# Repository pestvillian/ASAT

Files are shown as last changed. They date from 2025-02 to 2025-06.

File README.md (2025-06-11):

**Automated Sample Agitation Transportation System**

We are an Electrical Engineering Capstone group from the University of California, Santa Cruz. Our project aims to design a more efficient, more cost-effective solution for medical staff and researchers to process human samples for imaging. 

Here is an overview of the file structure:
  - Five folders for each group member
  - "Motor-Controller-Board" contains PCB files for the Motor Controller PCB
  - "Touchscreen-Hardware" contains PCB files for the two revisions of the touchscreen PCB
  - "Firmware" contains the firmware for both PCBs

Finally, we created a poster to visually explain our project!

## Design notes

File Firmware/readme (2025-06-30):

To navigate the STM32 firmware folder,
Click on "Core" -> "SRC" -> "main.c" for the main file written by Dorjee Tenzing

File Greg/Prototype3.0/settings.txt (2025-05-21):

C:/Users/Greg/Desktop/ASAT/Greg/Prototype3.0/TempDirectory

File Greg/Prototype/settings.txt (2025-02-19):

C:/Users/geziegle/Desktop/ASAT/Greg/Prototype/Temp_directory

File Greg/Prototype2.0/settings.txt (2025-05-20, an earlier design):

C:/Users/Greg/Desktop/ASAT/Greg/Prototype2.0/temp_directory

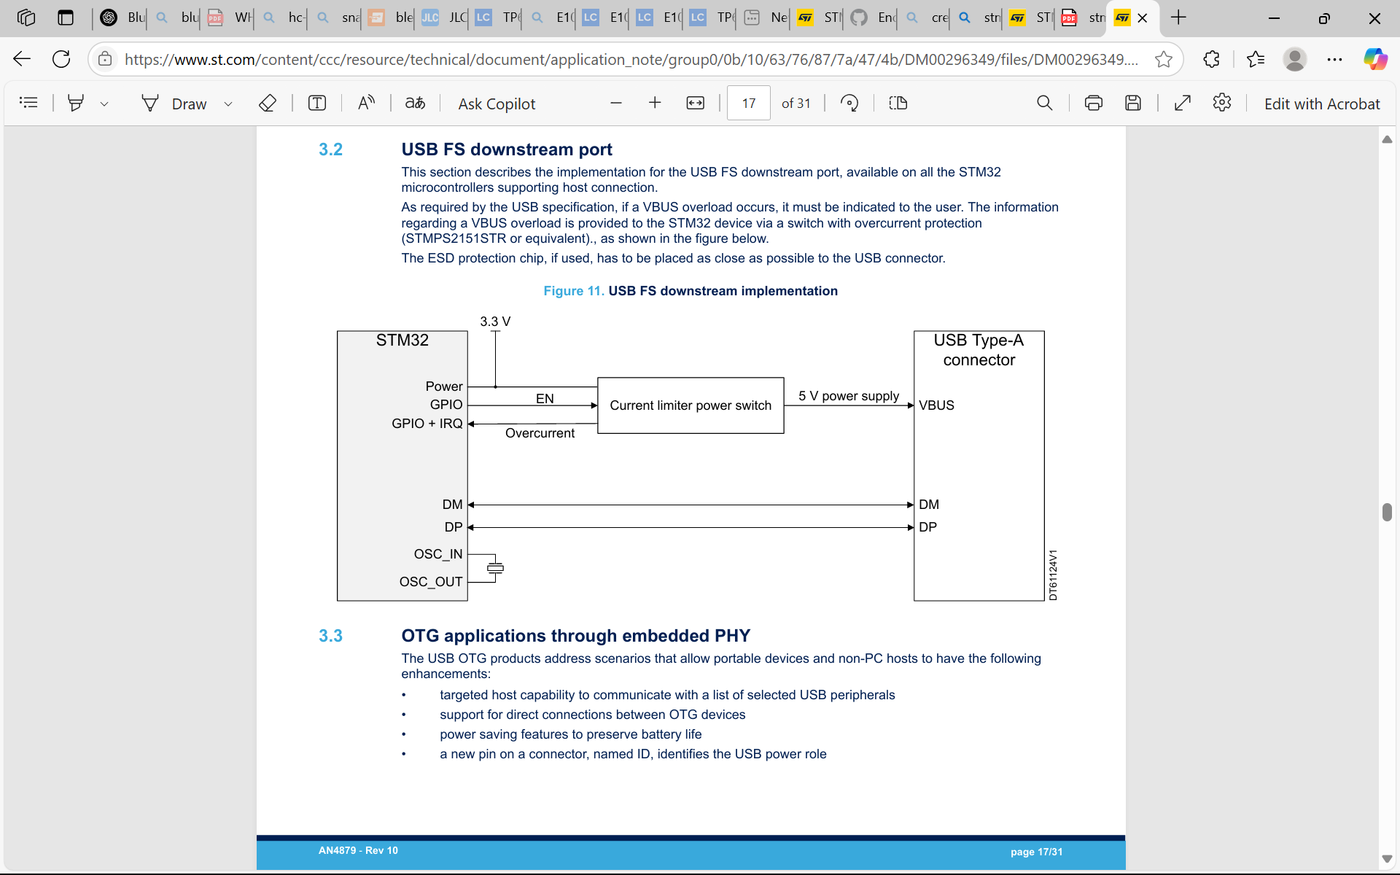
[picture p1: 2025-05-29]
Dorjee/datasheet_printouts/Touchscreen PCB Redesign/USB_OTG_FS Reference Circuit.png

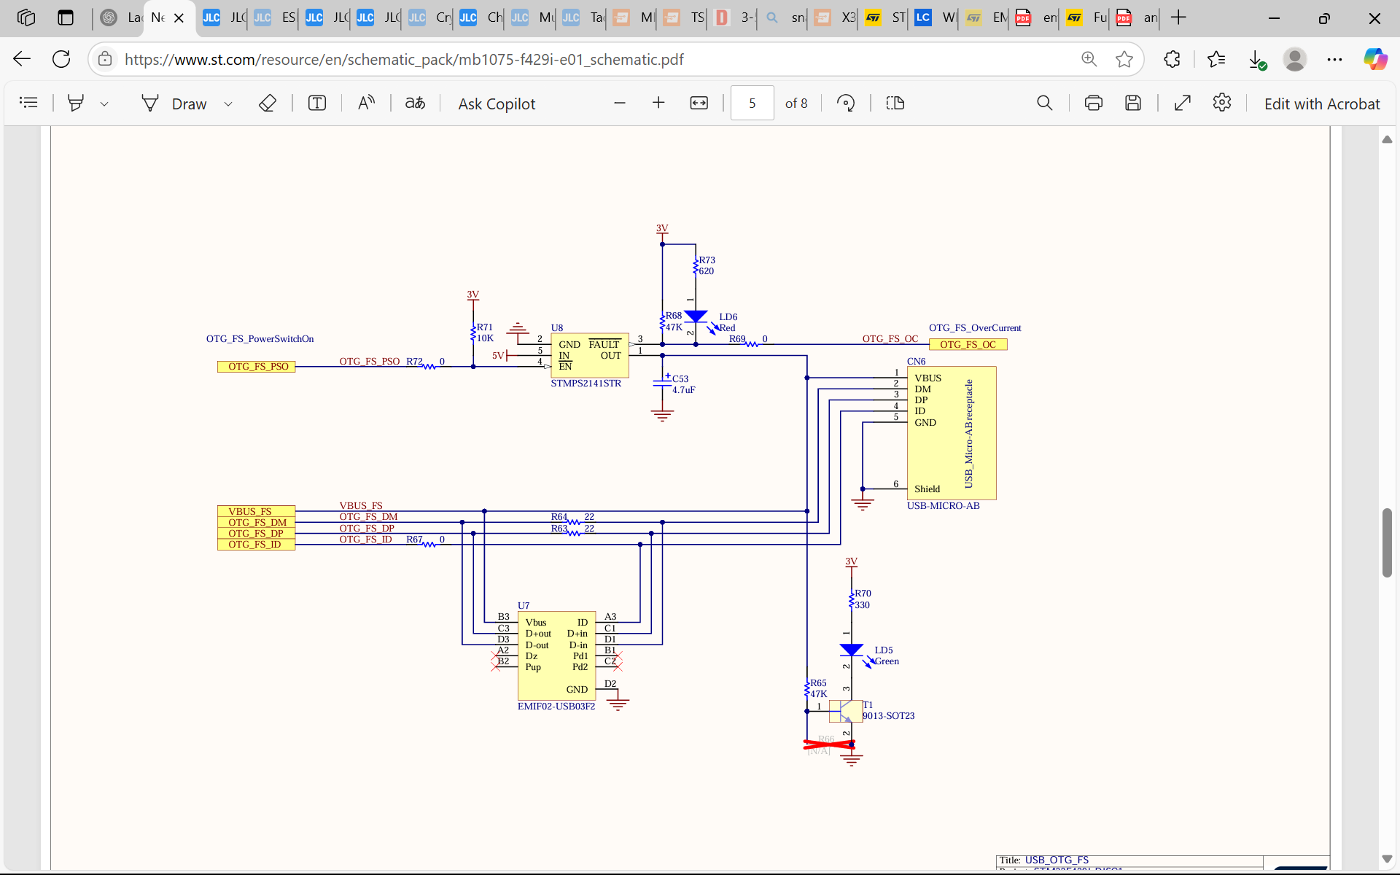
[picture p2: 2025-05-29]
Dorjee/datasheet_printouts/Touchscreen PCB Redesign/Disc Board USB Reference Circuit.png

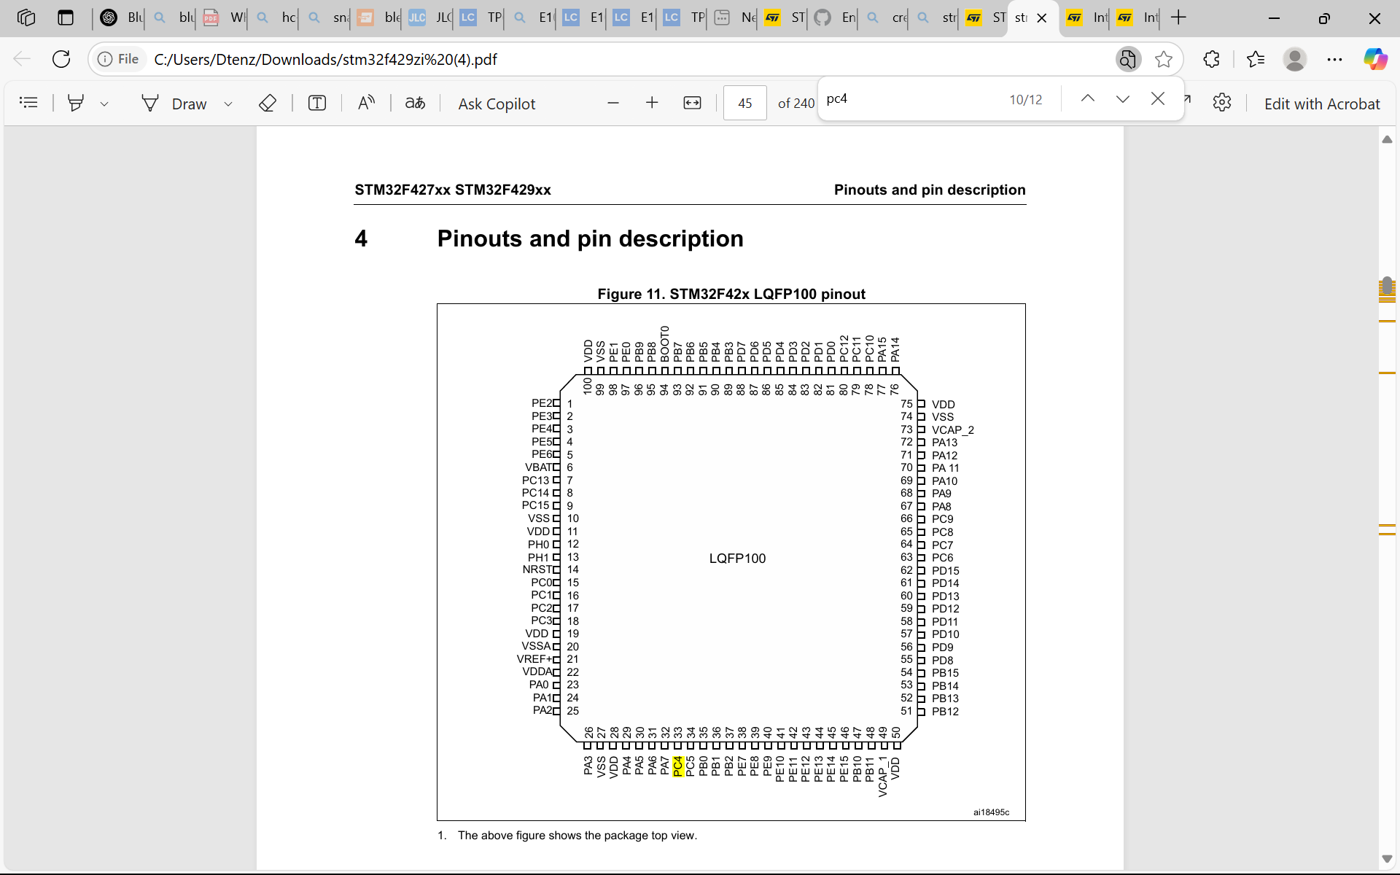
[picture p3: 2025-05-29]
Dorjee/datasheet_printouts/Touchscreen PCB Redesign/STM32F429VIT6 Pinout.png

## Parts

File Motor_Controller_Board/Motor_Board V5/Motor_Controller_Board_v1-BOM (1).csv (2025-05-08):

Reference | Qty | Value | DNP | Footprint | Datasheet | MPN | LCSC Part Number | Manufacturer
U401,U402,U403 | 3 | A4988 |  | Package_DFN_QFN:QFN-28-1EP_5x5mm_P0.5mm_EP3.25x3.25mm_ThermalVias | kicad-embed://A4988-Datasheet.pdf | A4988SETTR-T | C38437 | Allegro MicroSystems, LLC
U301 | 1 | ESP32-C6-MINI-1 |  | Espressif:ESP32-C6-MINI-1U | https://www.espressif.com/sites/default/files/documentation/esp32-c6-mini-1_mini-1u_datasheet_en.pdf | ESP32-C6-MINI-1U-H4 | C20627095 | Espressif Systems
U202 | 1 | AMS1117 |  | Package_TO_SOT_SMD:SOT-223-3_TabPin2 | http://www.advanced-monolithic.com/pdf/ds1117.pdf | AMS1117-3.3 | C6186 | Advanced Monolithic Systems
U201 | 1 | TP6841S6 |  | Package_TO_SOT_SMD:SOT-23-6 | https://jlcpcb.com/api/file/downloadByFileSystemAccessId/8588919820586377216 | TP6841S6-A | C2844924 | TECH PUBLIC
SW301,SW302 | 2 | SW_Push |  | Button_Switch_SMD:SW_Push_1P1T_XKB_TS-1187A | ~ | TS-1187A-B-A-B | C318884 | XKB Connection
R417 | 1 | 12k |  | Resistor_SMD:R_0603_1608Metric | ~ | 0603WAF1202T5E | C22790 | UNI-ROYAL(Uniroyal Elec)
R409,R410,R412,R414,R421,R422 | 6 | 75m |  | Resistor_SMD:R_1206_3216Metric | ~ | CR1206FR075P05R | C149663 | Ever Ohms Tech
R406,R408,R420 | 3 | 24k |  | Resistor_SMD:R_0603_1608Metric | ~ | 0603WAF2402T5E | C23352 | UNI-ROYAL(Uniroyal Elec)
R405,R407,R419 | 3 | 10R |  | Resistor_SMD:R_0603_1608Metric | ~ | 0603WAF100JT5E | C22859 | UNI-ROYAL(Uniroyal Elec)
R403 | 1 | 18k |  | Resistor_SMD:R_0603_1608Metric | ~ | 0603WAF1802T5E | C25810 | UNI-ROYAL(Uniroyal Elec)
R402,R404,R418 | 3 | 4k7 |  | Resistor_SMD:R_0603_1608Metric | ~ | 0603WAF4701T5E | C23162 | UNI-ROYAL(Uniroyal Elec)
R302,R303 | 2 | 0R |  | Resistor_SMD:R_0603_1608Metric | ~ | 0603WAF0000T5E | C21189 | UNI-ROYAL(Uniroyal Elec)
R301,R304,R401,R411,R415,R423 | 6 | 10k |  | Resistor_SMD:R_0603_1608Metric | ~ | 0603WAF1002T5E | C25804 | UNI-ROYAL(Uniroyal Elec)
R204 | 1 | 13k |  | Resistor_SMD:R_0603_1608Metric | ~ | 0603WAF1302T5E | C22797 | UNI-ROYAL(Uniroyal Elec)
R203 | 1 | 68k |  | Resistor_SMD:R_0603_1608Metric | ~ | 0603WAF6802T5E | C23231 | UNI-ROYAL(Uniroyal Elec)
R202,R413,R416,R424 | 4 | 100k |  | Resistor_SMD:R_0603_1608Metric | ~ | 0603WAF1003T5E | C25803 | UNI-ROYAL(Uniroyal Elec)
R201 | 1 | 5k1 |  | Resistor_SMD:R_0603_1608Metric | ~ | 0603WAF5101T5E | C23186 | UNI-ROYAL(Uniroyal Elec)
L201 | 1 | 22u |  | Inductor_SMD:L_10.4x10.4_H4.8 | ~ | SMDRH105R-220MT | C10165 | SXN(Shun Xiang Nuo Elec)
J302 | 1 | USB_B_Micro |  | Connector_USB:USB_Micro-B_Molex-105017-0001 | ~ | MicroXNJ | C404969 | SHOU HAN
D401,D402,D403 | 3 | SMAJ28A |  | Diode_SMD:D_SMA | ~ | SMAJ28A | C148227 | Littelfuse
D303 | 1 | SS14 |  | Diode_SMD:D_SMA | ~ | SS14 | C2480 | MDD(Microdiode Semiconductor)
D301,D302,D304 | 3 | PSM712-LF-T7 |  | Package_TO_SOT_SMD:SOT-23 | ~ | PSM712-LF-T7 | C32677 | ProTek Devices
D201 | 1 | RED |  | LED_SMD:LED_0603_1608Metric | ~ | KT-0603R | C2286 | Hubei KENTO Elec
C410,C415,C423 | 3 | 100u |  | Capacitor_SMD:CP_Elec_6.3x7.7 | ~ | RVT1V101M0607 | C3339 | Honor Elec
C407,C411,C420 | 3 | 220n |  | Capacitor_SMD:C_0805_2012Metric | ~ | CL21B224KBFNNNE | C5378 | Samsung Electro-Mechanics
C304 | 1 | 1u |  | Capacitor_SMD:C_0402_1005Metric | ~ | CL05A105KA5NQNC | C52923 | Samsung Electro-Mechanics
C301,C303,C305,C401,C403,C417 | 6 | 100n |  | Capacitor_SMD:C_0402_1005Metric | ~ | CL05B104KO5NNNC | C1525 | Samsung Electro-Mechanics
C205,C206,C302,C402,C404,C418 | 6 | 22u |  | Capacitor_SMD:C_0603_1608Metric | ~ | CL21A226MAQNNNE | C45783 | Samsung Electro-Mechanics
C202,C204 | 2 | 22u |  | Capacitor_SMD:C_2220_5750Metric | ~ | FS55X226K500EHG | C784103 | PSA(Prosperity Dielectrics)
C201,C203,C405,C406,C408,C409,C412,C413,C414,C416,C419,C421,C422,C424 | 14 | 100n |  | Capacitor_SMD:C_0603_1608Metric | ~ | CC0603KRX7R9BB104 | C14663 | YAGEO

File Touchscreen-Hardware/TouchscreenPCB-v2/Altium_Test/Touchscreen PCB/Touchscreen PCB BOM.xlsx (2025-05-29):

Designator | Name | Description | Manufacturer | Manufacturer Part Number | LCSC
C1 | 100n | Capacitor SMD 0402 | Samsung Electro-Mechanics | CL05B104KO5NNNC | C1525
C2 | 10u | Capacitor SMD 0603 | *Samsung Electro-Mechanics | CL10A106MA8NRNC | C96446
C3 | 22u | Capacitor SMD 0805 | Samsung Electro-Mechanics | CL21A226MAQNNNE | C45783
C4 | 22u | Capacitor SMD 0805 | Samsung Electro-Mechanics | CL21A226MAQNNNE | C45783
C5 | 10u | Capacitor SMD 0603 | *Samsung Electro-Mechanics | CL10A106MA8NRNC | C96446
C6 | 100n | Capacitor SMD 0402 | Samsung Electro-Mechanics | CL05B104KO5NNNC | C1525
C7 | 100n | Capacitor SMD 0402 | Samsung Electro-Mechanics | CL05B104KO5NNNC | C1525
C8 | 100n | Capacitor SMD 0402 | Samsung Electro-Mechanics | CL05B104KO5NNNC | C1525
C9 | 100n | Capacitor SMD 0402 | Samsung Electro-Mechanics | CL05B104KO5NNNC | C1525
C10 | 100n | Capacitor SMD 0402 | Samsung Electro-Mechanics | CL05B104KO5NNNC | C1525
C11 | 100n | Capacitor SMD 0402 | Samsung Electro-Mechanics | CL05B104KO5NNNC | C1525
C12 | 100n | Capacitor SMD 0402 | Samsung Electro-Mechanics | CL05B104KO5NNNC | C1525
C13 | 10u | Capacitor SMD 0603 | *Samsung Electro-Mechanics | CL10A106MA8NRNC | C96446
C14 | 1u | Capacitor SMD 0402 | Samsung Electro-Mechanics | CL05A105KA5NQNC | C52923
C15 | 100n | Capacitor SMD 0402 | Samsung Electro-Mechanics | CL05B104KO5NNNC | C1525
C16 | 10p | Capacitor SMD 0402 | Samsung Electro-Mechanics | CL05C100JB5NNNC | C32949
C17 | 10p | Capacitor SMD 0402 | Samsung Electro-Mechanics | CL05C100JB5NNNC | C32949
C18 | 2u2 | Capacitor SMD 0603 | Samsung Electro-Mechanics | CL10A225KO8NNNC | C23630
C19 | 2u2 | Capacitor SMD 0603 | Samsung Electro-Mechanics | CL10A225KO8NNNC | C23630
C20 | 100n | Capacitor SMD 0402 | Samsung Electro-Mechanics | CL05B104KO5NNNC | C1525
C21 | 4u7 | Capacitor SMD 0603 | Samsung Electro-Mechanics | CL10A475KO8NNNC | C19666
D1 | RED | LED 0603 RED SMD | Hubei KENTO Elec | KT-0603R | C2286
D2 | SMBJ6.5CA | 53.57A 600W 11.2V 7.22V Bidirectional 6.5V SMB ESD and Surge Protection (TVS/ESD) ROHS | hongjiacheng | SMBJ6.5CA | C7420377
D3 | SMBJ6.5CA | 53.57A 600W 11.2V 7.22V Bidirectional 6.5V SMB ESD and Surge Protection (TVS/ESD) ROHS | hongjiacheng | SMBJ6.5CA | C7420377
D4 | SMBJ6.5CA | 53.57A 600W 11.2V 7.22V Bidirectional 6.5V SMB ESD and Surge Protection (TVS/ESD) ROHS | hongjiacheng | SMBJ6.5CA | C7420377
FB1 | 120R | Ferrite Bead SMD 0603 | Murata Electronics | BLM18PG121SN1D | C14709
J1 | SSW-117-01-T-D | SQ Post Socket, Through-hole, Vertical, -55 to 105 degC, 2.54 mm Pitch, 34-Pin, Female, RoHS | Samtec
J2 | 473460001 | CONN RCPT USB2.0 MICRO B SMD R/A | Molex | 473460001 | C132560
P1 | 22-23-2021 | Male Header, Pitch 2.54 mm, 1 x 2 Position, Height 10.67 mm, Tail Length 3.56 mm, 0 to 75 degC, RoHS, Bulk
P2 | 61300611121
P3 | 22-27-2041 | Male Header, Pitch 2.54 mm, 1 x 4 Position, Height 11.7 mm, Tail Length 3.56 mm, RoHS, Bulk | Molex
R1 | 4k7 | Resistor SMD 0402 | UNI-ROYAL(Uniroyal Elec) | 0402WGF4701TCE | C25900
R2 | 220 | Resistor SMD 0402 | UNI-ROYAL(Uniroyal Elec) | 0402WGF2200TCE | C25091
R3 | 220 | Resistor SMD 0402 | UNI-ROYAL(Uniroyal Elec) | 0402WGF2200TCE | C25091
R4 | 10k | Resistor SMD 0402 | UNI-ROYAL(Uniroyal Elec) | 0402WGF1002TCE | C25744
R5 | 10k | Resistor SMD 0402 | UNI-ROYAL(Uniroyal Elec) | 0402WGF1002TCE | C25744
R6 | 47k | Resistor SMD 0402 | UNI-ROYAL(Uniroyal Elec) | 0402WGF4702TCE | C25792
R7 | 0 | Resistor SMD 0402 | UNI-ROYAL(Uniroyal Elec) | 0402WGF0000TCE | C17168
SW1 |  | None Without 50mA 5.1mm 100000 Times 160gf 12V 5.1mm 1.5mm Round Button Standing paste SPST SMD Tactile Switches ROHS | XKB Connection | TS-1187A-B-A-B | C318884
U1 | AMS1117-3.3 | LDO Voltage Regulators 1A, 3.3V | Advanced Monolithic Systems | AMS1117-3.3 | C6186
U2 | STM32F429VIT6 | ARM Cortex-M4 32-bit MCU+FPU, 225 DMIPS, 2048 kB Flash, 256 kB Internal RAM, 82 I/Os, 100-pin LQFP, -40 to 85 degC, Tray | STMicroelectronics | STM32F429VIT6 | C92002
U3 | STMPS2141STR | STMPS2141STR STMPS Series 1 Channel 5.5 V 500 mA 200 mOhm High Side Power Switch - SOT-23-5 | STMicroelectronics | STMPS2141STR | C54624
X1 | 16MHz |  | YXC Crystal Oscillators | X322516MLB4SI | C13738

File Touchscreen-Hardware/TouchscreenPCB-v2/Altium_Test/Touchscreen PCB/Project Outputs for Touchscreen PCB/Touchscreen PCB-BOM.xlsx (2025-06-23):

Designator | Quantity | Name | Description | Manufacturer | Manufacturer Part Number | LCSC | Manufacturer 1 | Manufacturer Part Number 1
C1, C6, C7, C8, C9, C10, C11, C12, C15, C20 | 10 | 100n | Capacitor SMD 0402 | Samsung Electro-Mechanics | CL05B104KO5NNNC | C1525
C2, C5, C13 | 3 | 10u | Capacitor SMD 0603 | *Samsung Electro-Mechanics | CL10A106MA8NRNC | C96446
C3, C4 | 2 | 22u | Capacitor SMD 0805 | Samsung Electro-Mechanics | CL21A226MAQNNNE | C45783
C14 | 1 | 1u | Capacitor SMD 0402 | Samsung Electro-Mechanics | CL05A105KA5NQNC | C52923
C16, C17 | 2 | 10p | Capacitor SMD 0402 | Samsung Electro-Mechanics | CL05C100JB5NNNC | C32949
C18, C19 | 2 | 2u2 | Capacitor SMD 0603 | Samsung Electro-Mechanics | CL10A225KO8NNNC | C23630
C21 | 1 | 4u7 | Capacitor SMD 0603 | Samsung Electro-Mechanics | CL10A475KO8NNNC | C19666
D1 | 1 | RED | LED 0603 RED SMD | Hubei KENTO Elec | KT-0603R | C2286
FB1 | 1 | 120R | Ferrite Bead SMD 0603 | Murata Electronics | BLM18PG121SN1D | C14709
J1 | 1 | 2x17 Odd-Even | SQ Post Socket, Through-hole, Vertical, -55 to 105 degC, 2.54 mm Pitch, 34-Pin, Female, RoHS | Samtec |  |  | Samtec | SSW-117-01-T-D
J2 | 1 | 473460001 | CONN RCPT USB2.0 MICRO B SMD R/A | Molex | 473460001 | C132560 | Molex | 47346-0001
J3 | 1 | 691102710002 |  |  |  |  | Wurth Electronics | 691102710002
J4, J5, J6 | 3 | B2B-XH-A(LF)(SN) | CONN HEADER VERT 2POS 2.5MM |  |  |  | JST | B2B-XH-A(LF)(SN)
J7 | 1 | B4B-XH-A(LF)(SN) | CONN HEADER VERT 4POS 2.5MM |  |  |  | JST | B4B-XH-A(LF)(SN)
P2 | 1 |  |  |  |  |  | Wurth Electronics | 61300611121
Q1 | 1 | IRLZ44NPbF | MOSFET N-CH 55V 47A TO220AB |  |  |  | Infineon | IRLZ44NPBF
R1 | 1 | 4k7 | Resistor SMD 0402 | UNI-ROYAL(Uniroyal Elec) | 0402WGF4701TCE | C25900
R2, R3 | 2 | 220 | Resistor SMD 0402 | UNI-ROYAL(Uniroyal Elec) | 0402WGF2200TCE | C25091
R4, R5, R9 | 3 | 10k | Resistor SMD 0402 | UNI-ROYAL(Uniroyal Elec) | 0402WGF1002TCE | C25744
R6 | 1 | 47k | Resistor SMD 0402 | UNI-ROYAL(Uniroyal Elec) | 0402WGF4702TCE | C25792
R7 | 1 | 0 | Resistor SMD 0402 | UNI-ROYAL(Uniroyal Elec) | 0402WGF0000TCE | C17168
R8 | 1 | 1k | Resistor SMD 0402 | UNI-ROYAL(Uniroyal Elec) | 0402WGF1001TCE | C11702
SW1 | 1 |  | None Without 50mA 5.1mm 100000 Times 160gf 12V 5.1mm 1.5mm Round Button Standing paste SPST SMD Tactile Switches ROHS | XKB Connection | TS-1187A-B-A-B | C318884
U1 | 1 | AMS1117-3.3 | LDO Voltage Regulators 1A, 3.3V | Advanced Monolithic Systems | AMS1117-3.3 | C6186 | Advanced Monolithic Systems | AMS1117-3.3
U2 | 1 | STM32F429VIT6 | ARM Cortex-M4 32-bit MCU+FPU, 225 DMIPS, 2048 kB Flash, 256 kB Internal RAM, 82 I/Os, 100-pin LQFP, -40 to 85 degC, Tray | STMicroelectronics | STM32F429VIT6 | C92002 | STMicroelectronics | STM32F429VIT6
U3 | 1 | STMPS2141STR | STMPS2141STR STMPS Series 1 Channel 5.5 V 500 mA 200 mOhm High Side Power Switch - SOT-23-5 | STMicroelectronics | STMPS2141STR | C54624 | STMicroelectronics | STMPS2141STR
X1 | 1 | 16MHz |  | YXC Crystal Oscillators | X322516MLB4SI | C13738

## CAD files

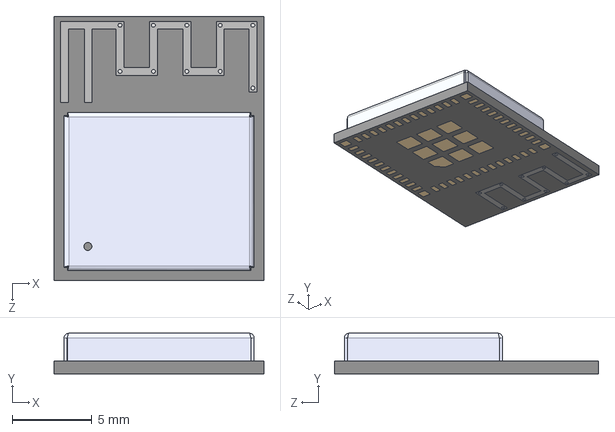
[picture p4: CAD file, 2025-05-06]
Motor_Controller_Board/Motor_Controller_Board/ESP32-C6-MINI-1-N4.STEP
13.2 x 2.55 x 16.6 mm

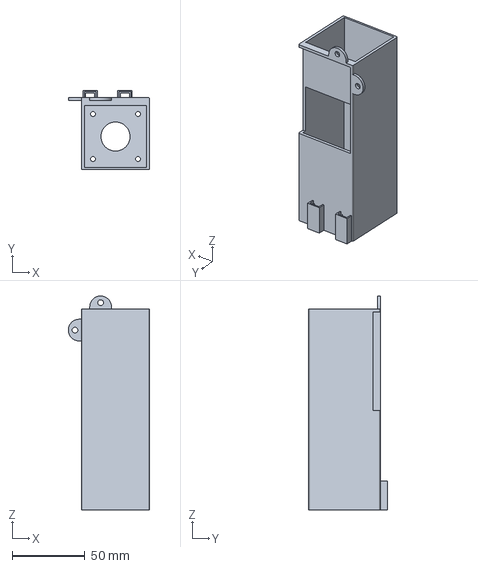
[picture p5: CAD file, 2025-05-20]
Greg/3DPrints-Exports/PrimaryBodyV6.3mf
56.0 x 54.7 x 147.3 mm

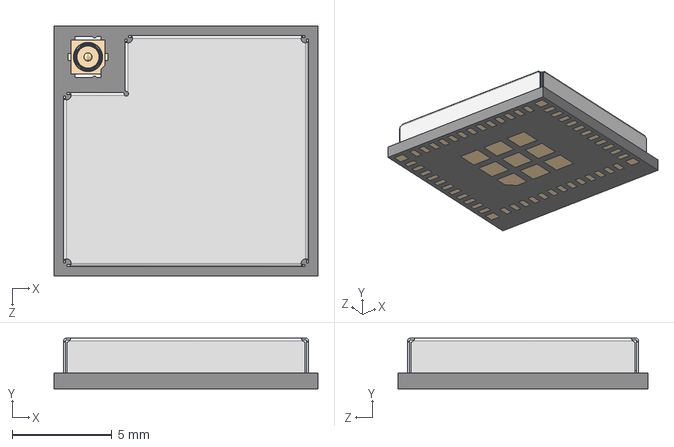
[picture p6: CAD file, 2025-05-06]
Motor_Controller_Board/Motor_Controller_Board/ESP32-C3-MINI-1U-N4--3DModel-STEP-269445.STEP
13.2 x 2.55 x 12.5 mm

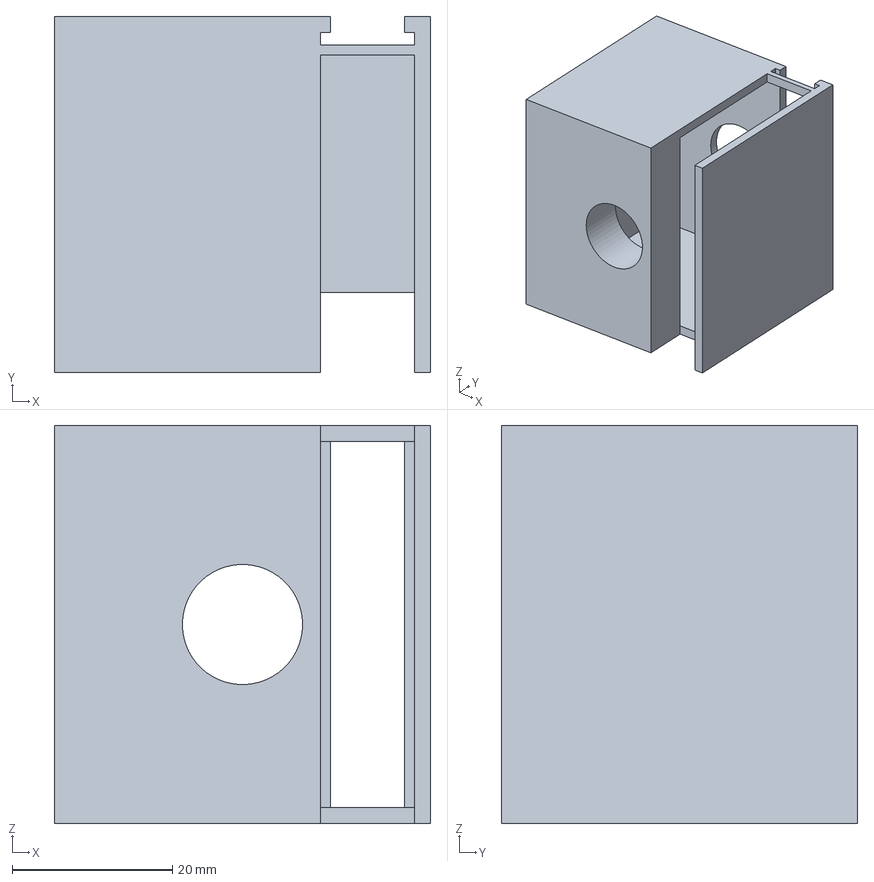
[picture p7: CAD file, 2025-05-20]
Greg/3DPrints-Exports/SecondaryBody2.3mf
47.0 x 44.5 x 49.7 mm

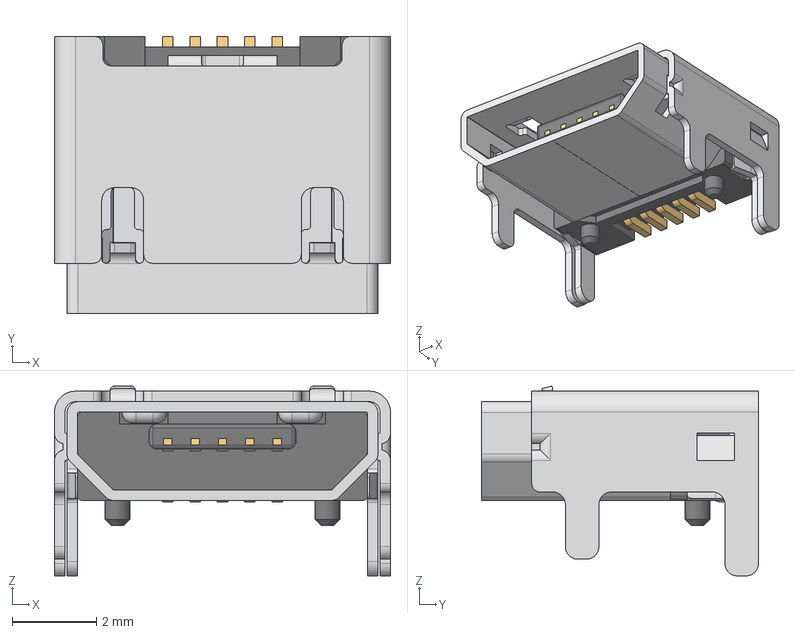
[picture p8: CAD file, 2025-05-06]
Motor_Controller_Board/Motor_Controller_Board/Download_STP_629105150521_rev1.stp
8.00 x 6.60 x 4.52 mm
629105150521_Housing
629105150521_Pin1 x 4
629105150521_Pin2
629105150521_Shielding2
629105150521_Shielding

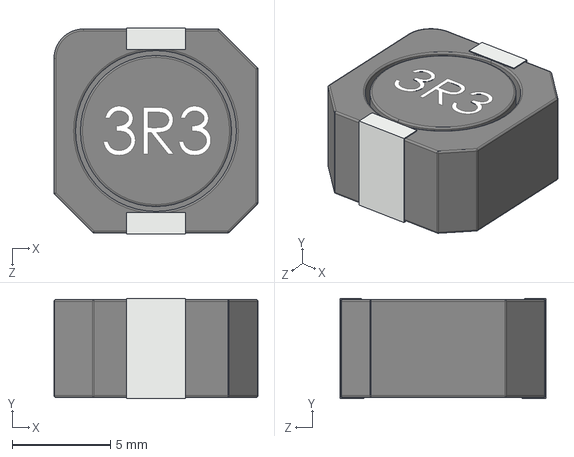
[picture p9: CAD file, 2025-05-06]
Motor_Controller_Board/Motor_Controller_Board/User Library-SMDRH105R.STEP
10.4 x 5.12 x 10.5 mm

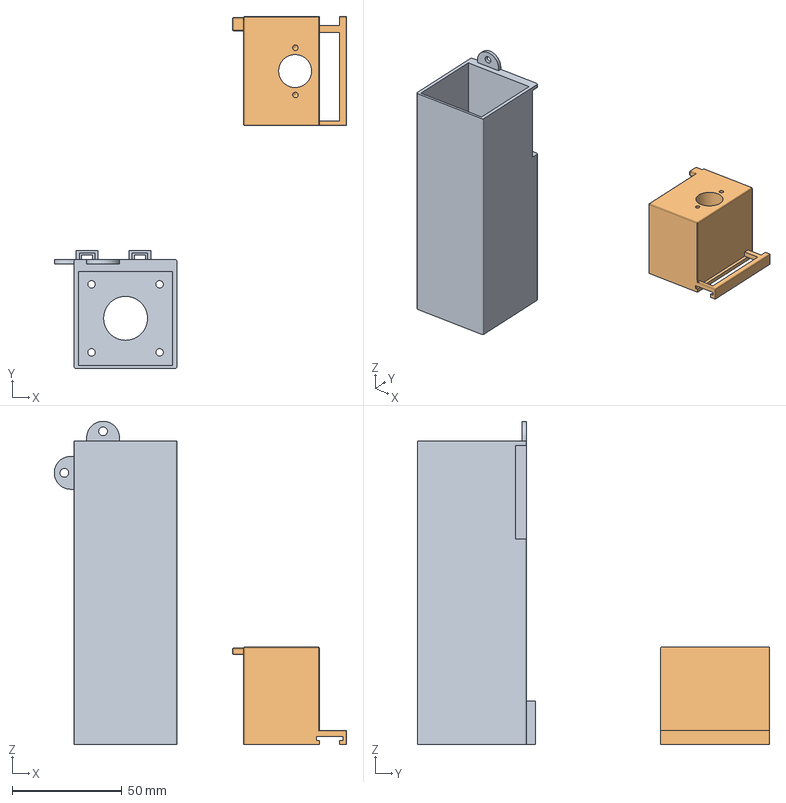
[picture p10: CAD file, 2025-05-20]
Greg/3DPrints-Exports/PrimarySecondaryBodies.3mf
133.2 x 160.3 x 147.3 mm
PrimaryBodyV4.stl
SecondaryBodyV4.stl

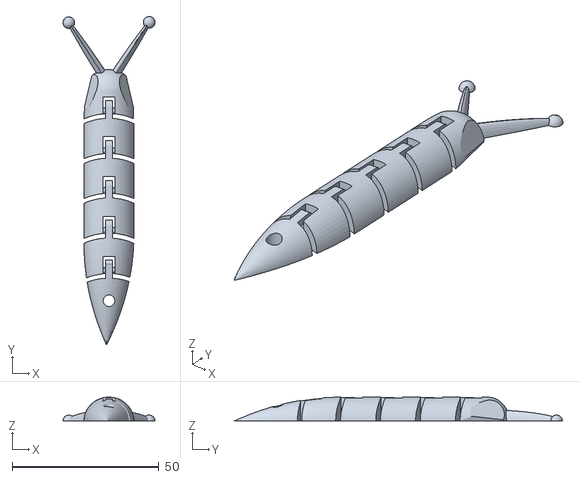
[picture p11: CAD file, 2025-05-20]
Greg/3DPrints-Exports/articulated_slug_key_chain.stl
31.4 x 111.9 x 8.12

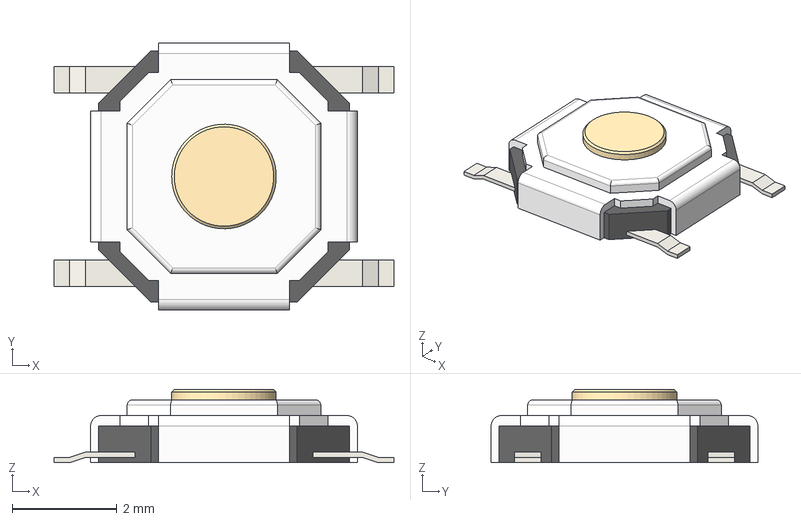
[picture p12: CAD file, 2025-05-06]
Motor_Controller_Board/Motor_Controller_Board/TS-1187A.step
6.50 x 5.10 x 1.40 mm

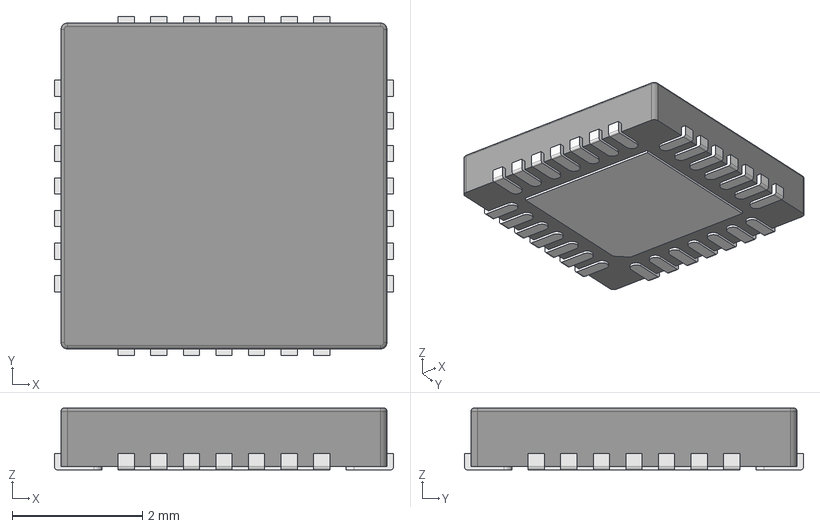
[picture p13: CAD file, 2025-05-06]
Motor_Controller_Board/Motor_Controller_Board/QFN28.step
5.20 x 5.20 x 0.95 mm

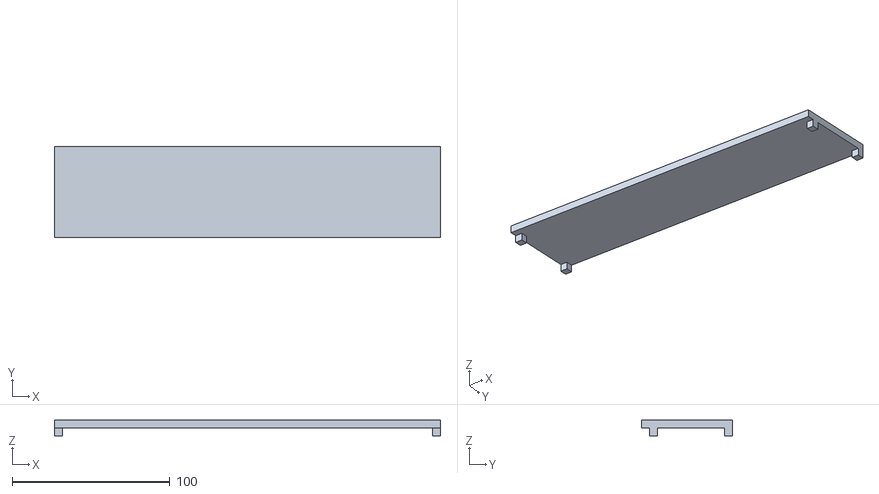
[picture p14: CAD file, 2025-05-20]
Greg/3DPrints-Exports/Drawer_Lid.stl
245.0 x 57.5 x 10.0

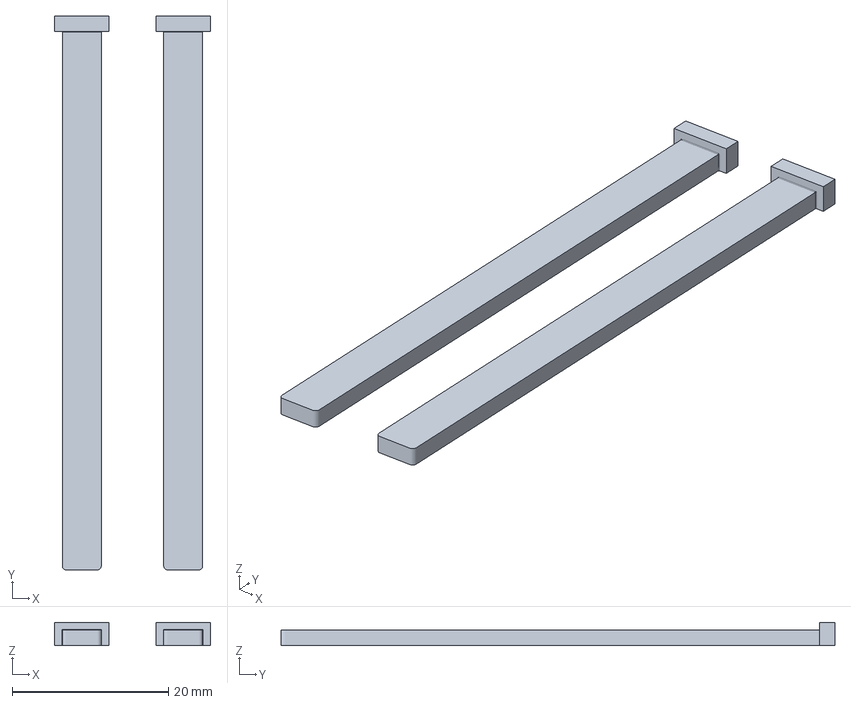
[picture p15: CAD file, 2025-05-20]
Greg/3DPrints-Exports/BackGuidesV2.3mf
20.0 x 71.0 x 3.00 mm

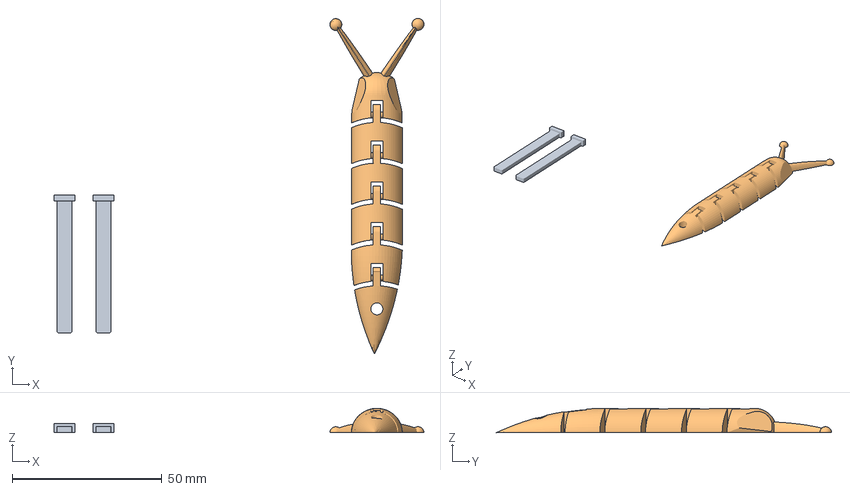
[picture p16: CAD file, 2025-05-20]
Greg/3DPrints-Exports/BackGuides.3mf
123.4 x 111.9 x 8.12 mm
BackGuides.stl
articulated_slug_key_chain.stl

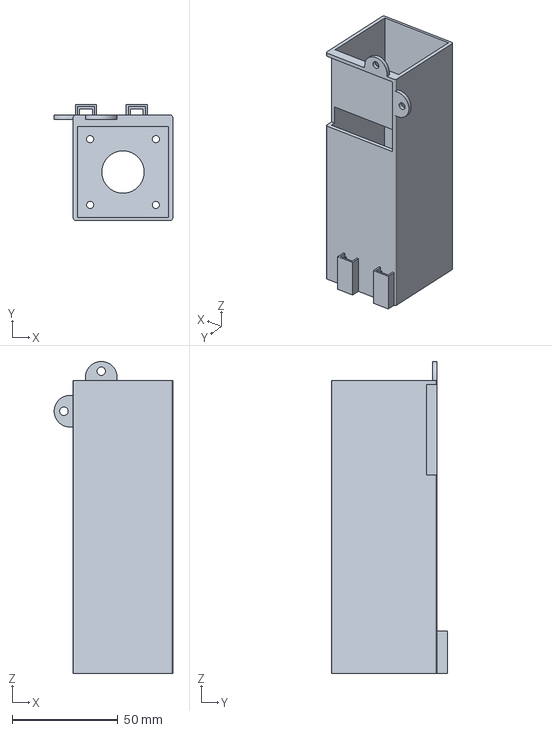
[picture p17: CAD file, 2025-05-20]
Greg/3DPrints-Exports/SecondaryBodyV5.3mf
56.0 x 54.7 x 147.3 mm

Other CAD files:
Greg/3DPrints-Exports/PrimaryBodyV9WLM.4.2.stl
Greg/3DPrints-Exports/scraper.gcode.3mf
Motor_Controller_Board/Motor_Controller_Board/Screw Terminal Block 5mm 2-way.step
Greg/3DPrints-Exports/BackGuides.stl
Greg/3DPrints-Exports/BackGuidesV2.stl
Greg/3DPrints-Exports/PrimaryBodyV4.stl
Greg/3DPrints-Exports/PrimaryBodyV5.stl
Greg/3DPrints-Exports/PrimaryBodyV6.stl
Greg/3DPrints-Exports/SecondaryBody2.stl
Greg/3DPrints-Exports/SecondaryBodyV3.3mf
Greg/3DPrints-Exports/SecondaryBodyV3.stl
Greg/3DPrints-Exports/SecondaryBodyV4.stl
Greg/3DPrints-Exports/SecondaryBodyV5.stl
Motor_Controller_Board/Motor_Controller_Board/Screw Terminal Block 5mm 4-way.step
Motor_Controller_Board/Motor_Controller_Board/User Library-SMDRH105R.sldprt
Motor_Controller_Board/motor_controller_board_3D/Screw Terminal Block 5mm 2-way.step
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

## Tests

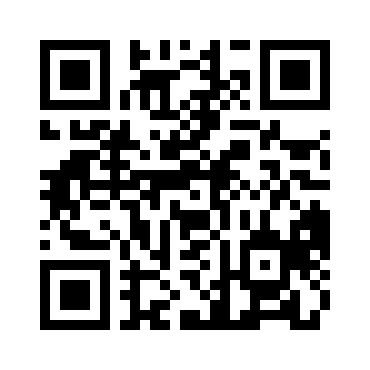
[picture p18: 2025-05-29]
Greg/KVgui/test_dir/test.exe_QR.png

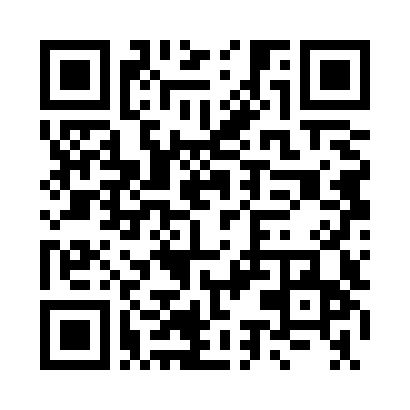
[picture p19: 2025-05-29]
Greg/KVgui/test_dir/my test_QR.png

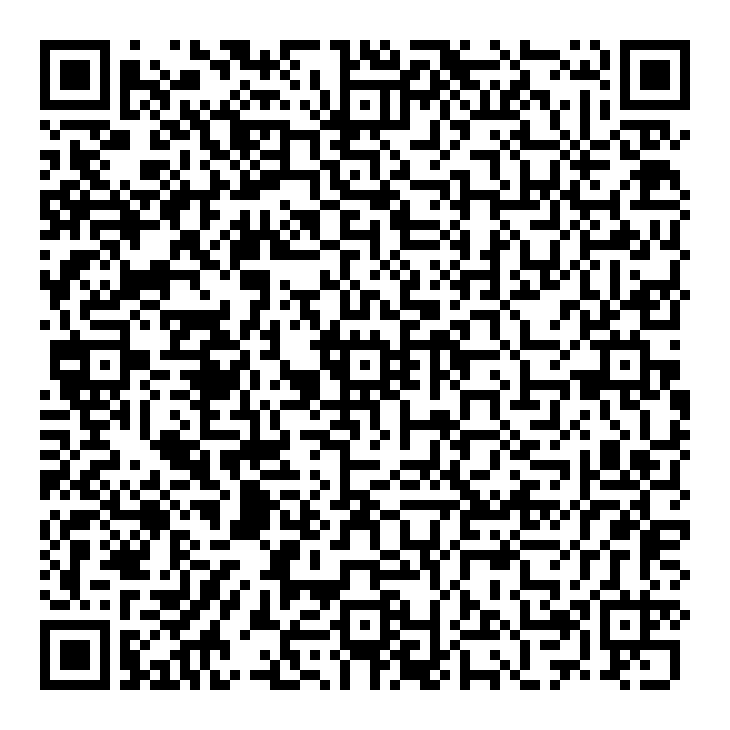
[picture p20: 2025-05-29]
Greg/KVgui/test_dir/gamze_QR.png

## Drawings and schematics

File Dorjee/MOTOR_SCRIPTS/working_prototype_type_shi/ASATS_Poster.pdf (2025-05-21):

## Agitation Body Design

# Automated Sample Agitation Transportation System:

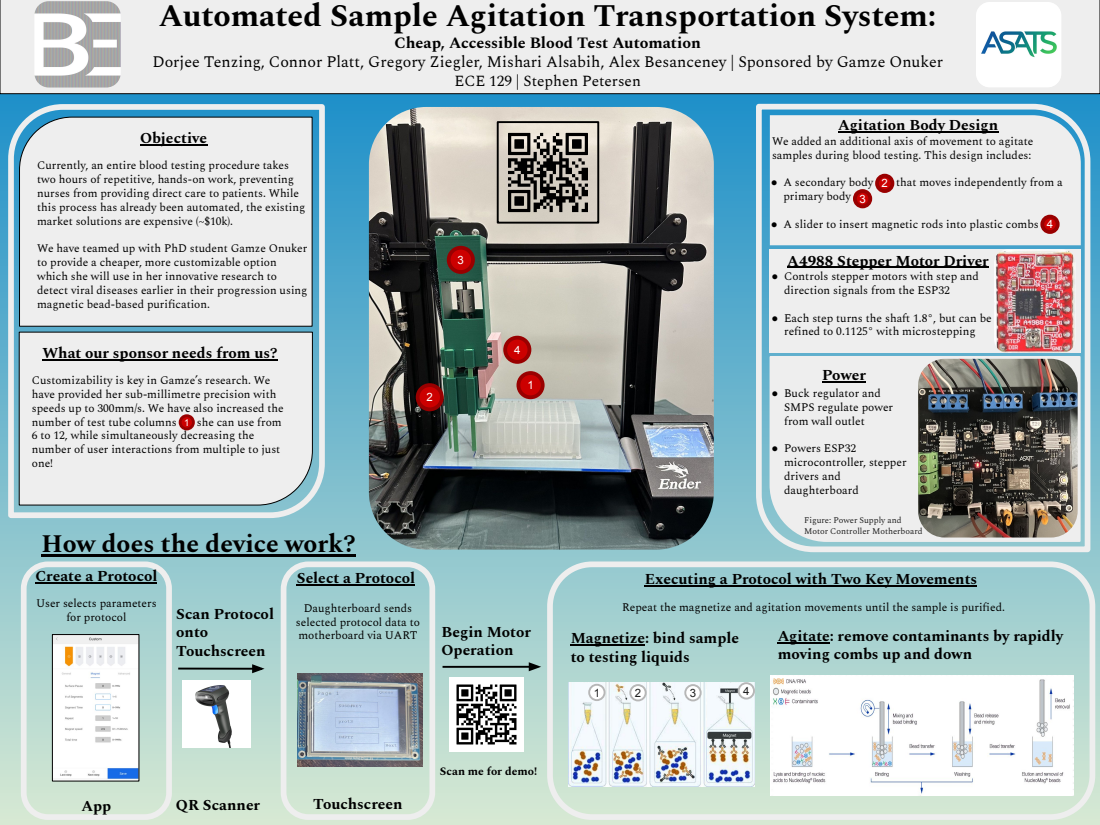
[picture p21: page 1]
Create a Protocol; App; Select a Protocol; Touchscreen; Scan Protocol onto Touchscreen; Begin Motor Operation; QR Scanner; Power; Objective

Cheap, Accessible Blood Test Automation

Dorjee Tenzing, Connor Platt, Gregory Ziegler, Mishari Alsabih, Alex Besanceney | Sponsored by Gamze Onuker

ECE 129 | Stephen Petersen

We added an additional axis of movement to agitate
samples during blood testing. This design includes:
● A secondary body (2) that moves independently from a
primary body (3).
● A slider to insert magnetic rods into plastic combs (4).
A4988 Stepper Motor Driver
● Controls stepper motors with step and
direction signals from the ESP32
● Each step turns the shaft 1.8°, but can be
refined to 0.1125° with microstepping

Currently, an entire blood testing procedure takes
two hours of repetitive, hands-on work, preventing
nurses from providing direct care to patients. While
this process has already been automated, the existing
market solutions are expensive (~$10k).
We have teamed up with PhD student Gamze Onuker
to provide a cheaper, more customizable option
which she will use in her innovative research to
detect viral diseases earlier in their progression using
magnetic bead-based purification.

What our sponsor needs from us?

Customizability is key in Gamze’s research. We
have provided her sub-millimetre precision with
speeds up to 300mm/s. We have also increased the
number of test tube columns (1) she can use from
6 to 12, while simultaneously decreasing the
number of user interactions from multiple to just
one!

● Buck regulator and
SMPS regulate power
from wall outlet
● Powers ESP32
microcontroller, stepper
drivers and
daughterboard

Figure: Power Supply and
Motor Controller Motherboard

How does the device work?

Executing a Protocol with Two Key Movements

User selects parameters
for protocol

Daughterboard sends
selected protocol data to
motherboard via UART

Repeat the magnetize and agitation movements until the sample is purified.
Magnetize: bind sample
to testing liquids

Agitate: remove contaminants by rapidly
moving combs up and down

Scan me for demo!

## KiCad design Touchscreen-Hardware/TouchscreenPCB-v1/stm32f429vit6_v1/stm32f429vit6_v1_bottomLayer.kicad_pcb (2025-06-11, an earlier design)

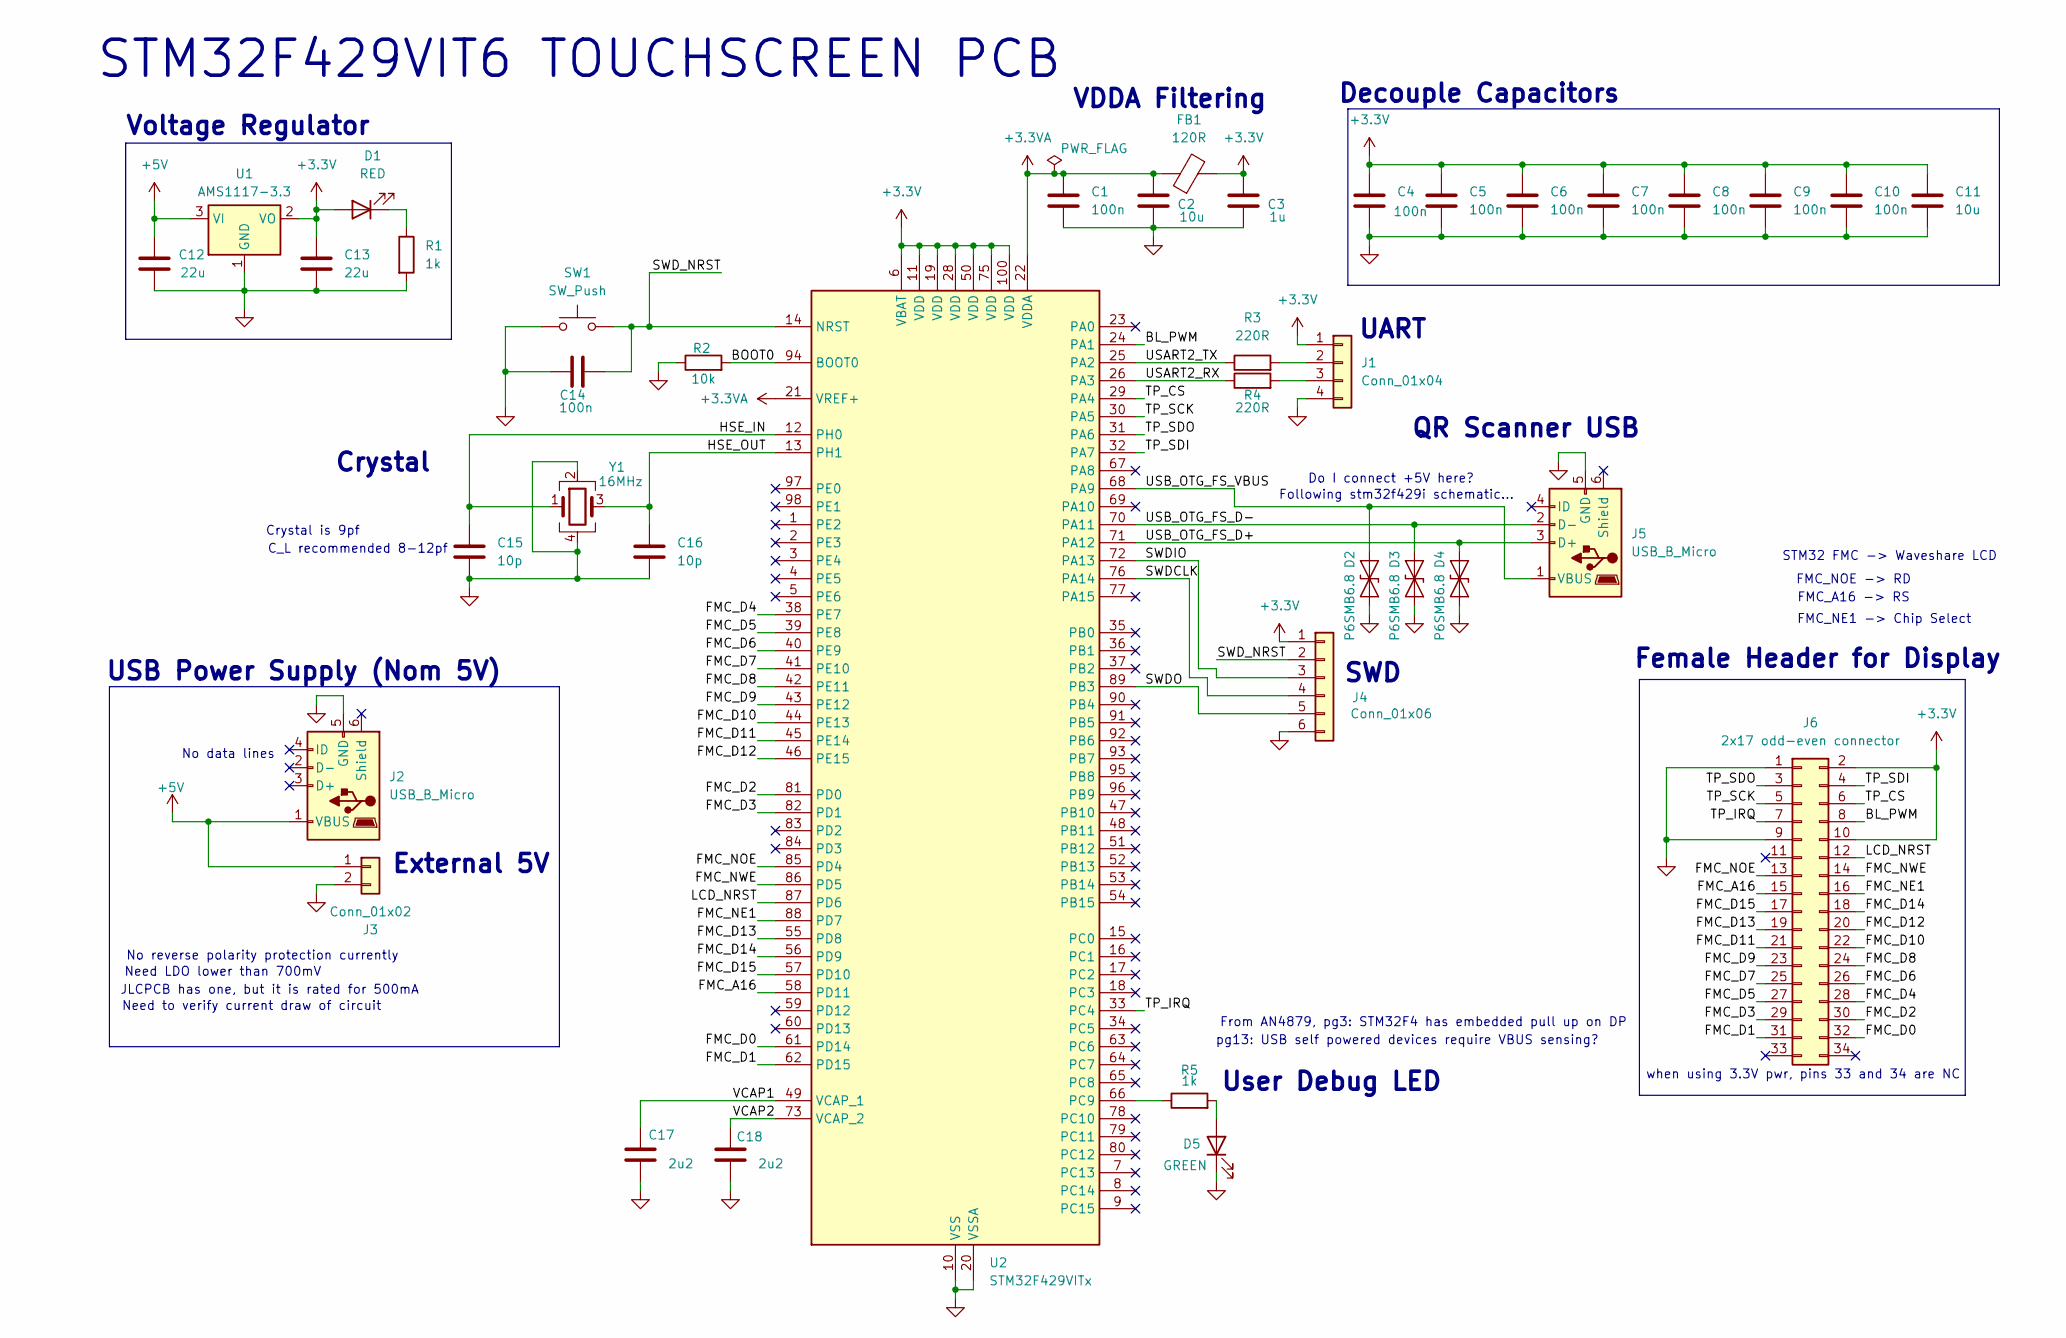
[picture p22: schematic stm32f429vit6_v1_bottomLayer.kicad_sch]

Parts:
C1, C4, C5, C6, C7, C8, C9, C10, C14: 100n; C_0402_1005Metric
C2, C11: 10u; C_0603_1608Metric
C3: 1u; C_0603_1608Metric
C12, C13: 22u; C_0603_1608Metric
C15, C16: 10p; C_0402_1005Metric
C17, C18: 2u2; C_0603_1608Metric
D1: RED; LED_0603_1608Metric
D2, D3, D4: P6SMB6.8; SOT-23
D5: GREEN; LED_0603_1608Metric
FB1: 120R; L_0805_2012Metric_Pad1.05x1.20mm_HandSolder
J1: Conn_01x04; PinHeader_1x04_P2.54mm_Vertical
J2, J5: USB_B_Micro; USB_Micro-B_Molex-105017-0001
J3: Conn_01x02; PinHeader_1x02_P2.54mm_Vertical
J4: Conn_01x06; PinHeader_1x06_P2.54mm_Vertical
J6: 2x17 odd-even connector; PinSocket_2x17_P2.54mm_Vertical
R1, R5: 1k; R_0805_2012Metric
R2: 10k; R_0805_2012Metric
R3, R4: 220R; R_0805_2012Metric
SW1: SW_Push; SW_Push_1P1T_XKB_TS-1187A
U1: AMS1117-3.3; SOT-223-3_TabPin2
U2: STM32F429VITx; LQFP-100_14x14mm_P0.5mm
Y1: 16MHz; Crystal_SMD_3225-4Pin_3.2x2.5mm_HandSoldering

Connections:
+3.3V: C3.1, C4.1, C5.1, C6.1, C7.1, C8.1, C9.1, C10.1, C11.1, C13.1, D1.2 (A), FB1.2, J1.1, J4.1, J6.2, J6.10, U1.2 (VO), U2.6 (VBAT), U2.11 (VDD), U2.19 (VDD), U2.28 (VDD), U2.50 (VDD), U2.75 (VDD), U2.100 (VDD)
+3.3VA: C1.1, C2.1, FB1.1, U2.21 (VREF+), U2.22 (VDDA)
+5V: C12.1, J2.1 (VBUS), J3.1, U1.3 (VI)
/BL_PWM: J6.8, U2.24 (PA1)
/BOOT0: R2.2, U2.94 (BOOT0)
/FMC_A16: J6.15, U2.58 (PD11)
/FMC_D0: J6.32, U2.61 (PD14)
/FMC_D1: J6.31, U2.62 (PD15)
/FMC_D2: J6.30, U2.81 (PD0)
/FMC_D3: J6.29, U2.82 (PD1)
/FMC_D4: J6.28, U2.38 (PE7)
/FMC_D5: J6.27, U2.39 (PE8)
/FMC_D6: J6.26, U2.40 (PE9)
/FMC_D7: J6.25, U2.41 (PE10)
/FMC_D8: J6.24, U2.42 (PE11)
/FMC_D9: J6.23, U2.43 (PE12)
/FMC_D10: J6.22, U2.44 (PE13)
/FMC_D11: J6.21, U2.45 (PE14)
/FMC_D12: J6.20, U2.46 (PE15)
/FMC_D13: J6.19, U2.55 (PD8)
/FMC_D14: J6.18, U2.56 (PD9)
/FMC_D15: J6.17, U2.57 (PD10)
/FMC_NE1: J6.16, U2.88 (PD7)
/FMC_NOE: J6.13, U2.85 (PD4)
/FMC_NWE: J6.14, U2.86 (PD5)
/HSE_IN: C15.1, U2.12 (PH0), Y1.1
/HSE_OUT: C16.1, U2.13 (PH1), Y1.3
/LCD_NRST: J6.12, U2.87 (PD6)
/SWDCLK: J4.4, U2.76 (PA14)
/SWDIO: J4.3, U2.72 (PA13)
/SWDO: J4.5, U2.89 (PB3)
/SWD_NRST: C14.2, J4.2, SW1.2, U2.14 (NRST)
/TP_CS: J6.6, U2.29 (PA4)
/TP_IRQ: J6.7, U2.33 (PC4)
/TP_SCK: J6.5, U2.30 (PA5)
/TP_SDI: J6.4, U2.32 (PA7)
/TP_SDO: J6.3, U2.31 (PA6)
/USART2_RX: R4.1, U2.26 (PA3)
/USART2_TX: R3.1, U2.25 (PA2)
/USB_OTG_FS_D+: D4.2 (A2), J5.3 (D+), U2.71 (PA12)
/USB_OTG_FS_D-: D3.2 (A2), J5.2 (D-), U2.70 (PA11)
/USB_OTG_FS_VBUS: D2.2 (A2), J5.1 (VBUS), U2.68 (PA9)
/VCAP1: C17.1, U2.49 (VCAP_1)
/VCAP2: C18.1, U2.73 (VCAP_2)
GND: C1.2, C2.2, C3.2, C4.2, C5.2, C6.2, C7.2, C8.2, C9.2, C10.2, C11.2, C12.2, C13.2, C14.1, C15.2, C16.2, C17.2, C18.2, D2.1 (A1), D3.1 (A1), D4.1 (A1), D5.1 (K), J1.4, J2.5 (GND), J3.2, J4.6, J5.5 (GND), J6.1, J6.9, R1.2, R2.1, SW1.1, U1.1 (GND), U2.10 (VSS), U2.20 (VSSA), U2.27 (VSS), U2.74 (VSS), U2.99 (VSS), Y1.2, Y1.4
unnamed: D1.1 (K), R1.1
unnamed: D5.2 (A), R5.2
unnamed: J1.2, R3.2
unnamed: J1.3, R4.2
unnamed: R5.1, U2.66 (PC9)

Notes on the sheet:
USB Power Supply (Nom 5V)
QR Scanner USB
STM32F429VIT6 TOUCHSCREEN PCB
STM32 FMC -> Waveshare LCD
Female Header for Display
No data lines
UART
FMC_NOE -> RD
Need LDO lower than 700mV
Do I connect +5V here?
pg13: USB self powered devices require VBUS sensing?
User Debug LED
No reverse polarity protection currently
when using 3.3V pwr, pins 33 and 34 are NC
Crystal is 9pf
External 5V
FMC_A16 -> RS
SWD
Voltage Regulator
Need to verify current draw of circuit
FMC_NE1 -> Chip Select
Crystal
Following stm32f429i schematic...
C_L recommended 8-12pf
From AN4879, pg3: STM32F4 has embedded pull up on DP
JLCPCB has one, but it is rated for 500mA
VDDA Filtering
Decouple Capacitors

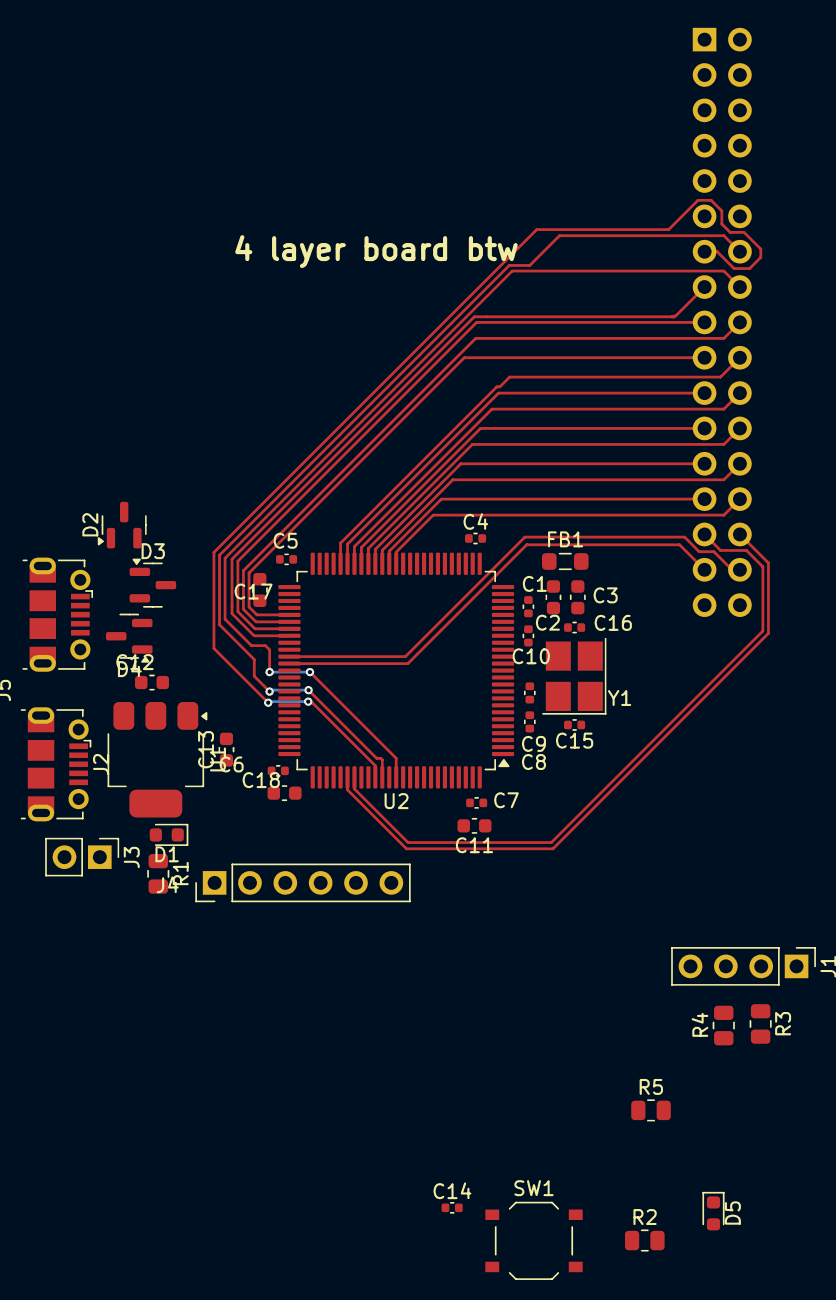
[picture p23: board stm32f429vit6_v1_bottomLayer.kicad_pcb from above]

Board: 4 copper layers, 39 parts (1 on the bottom side), 50 nets.

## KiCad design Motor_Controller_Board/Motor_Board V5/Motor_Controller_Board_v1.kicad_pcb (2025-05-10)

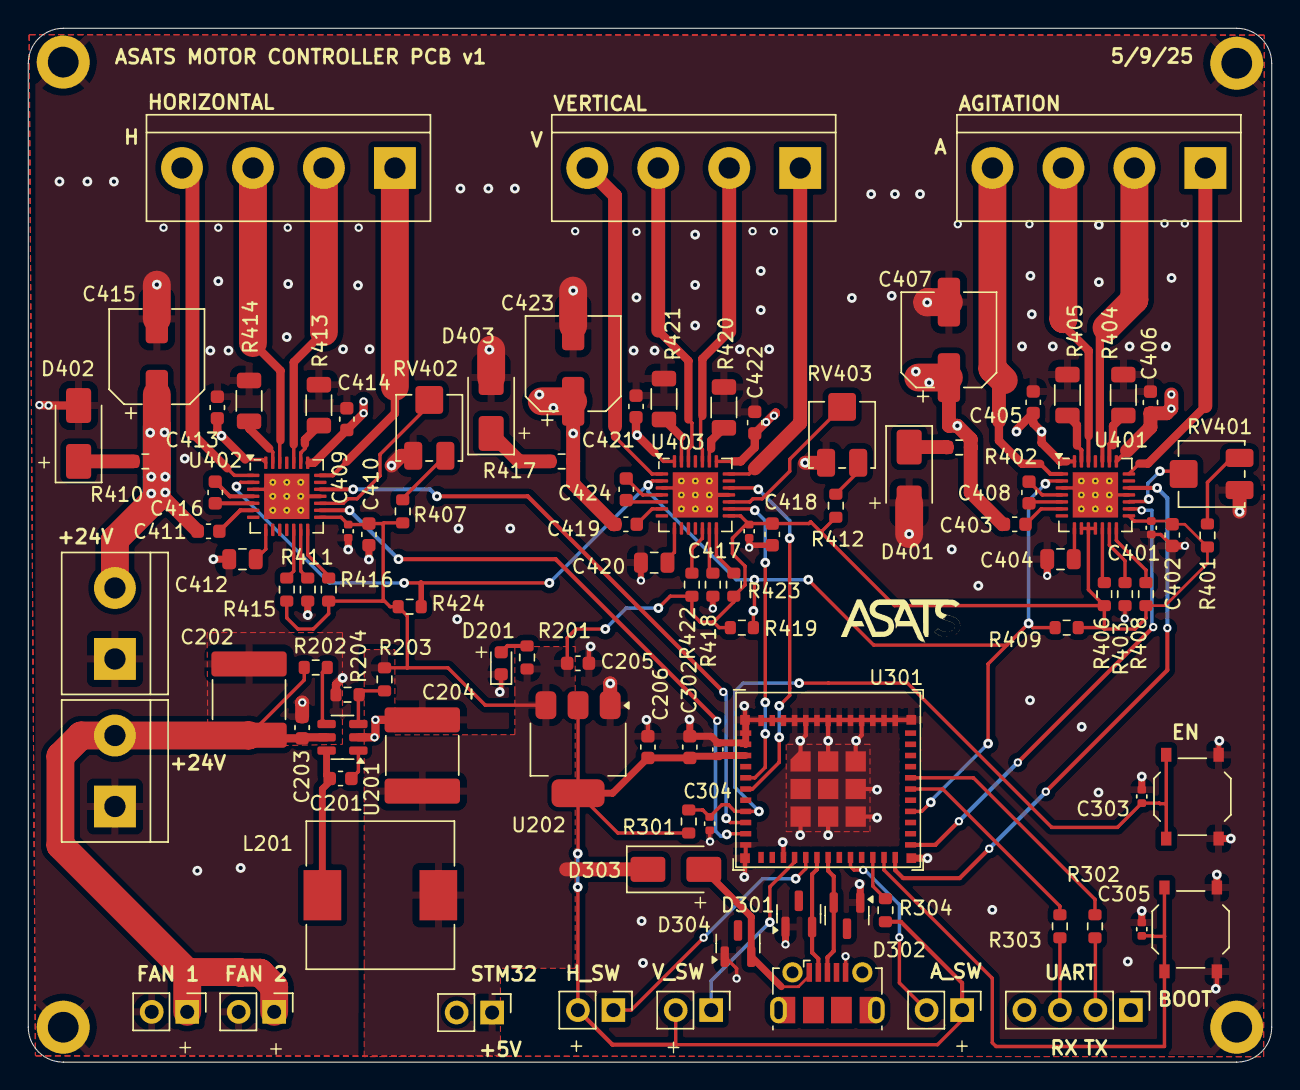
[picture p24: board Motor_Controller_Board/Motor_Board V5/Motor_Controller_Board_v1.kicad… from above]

Board: 2 copper layers, 89.0 x 74.0 mm, 104 parts (0 on the bottom side), 78 nets.

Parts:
C201, C203, C403, C405, C406, C408, C411, C413, C414, C416, C419, C421, C422, C424: 100n; C_0603_1608Metric
C202, C204: 22u; C_2220_5750Metric
C205, C206, C302, C402, C410, C418: 10u; C_0603_1608Metric
C301, C303, C305, C401, C409, C417: 100n; C_0402_1005Metric
C304: 1u; C_0402_1005Metric
C404, C412, C420: 220n; C_0805_2012Metric
C407, C415, C423: 100u; CP_Elec_6.3x7.7
D201: RED; LED_0603_1608Metric
D301, D302, D304: PSM712-LF-T7; SOT-23
D303: SS14; D_SMA
D401, D402, D403: SMAJ28A; D_SMA
H201, H202, H203, H204: MountingHole_Pad; MountingHole_2.2mm_M2_DIN965_Pad
J201, J203: Conn_01x02; TerminalBlock_bornier-2_P5.08mm
J202, J206, J207, J303, J304, J305: Conn_01x02; PinHeader_1x02_P2.54mm_Vertical
J301: Conn_01x04; PinHeader_1x04_P2.54mm_Vertical
J302: USB_B_Micro; USB_Micro-B_Molex-105017-0001
J401, J402, J403: Conn_01x04; TerminalBlock_bornier-4_P5.08mm
L201: 22u; L_10.4x10.4_H4.8
R201: 5k1; R_0603_1608Metric
R202, R408, R409, R416, R419, R423, R424: 100k; R_0603_1608Metric
R203: 68k; R_0603_1608Metric
R204: 13k; R_0603_1608Metric
R301, R304, R406, R415, R422: 10k; R_0603_1608Metric
R302, R303: 0R; R_0603_1608Metric
R401, R407, R412: 15k; R_0603_1608Metric
R402, R410, R417: 10R; R_0603_1608Metric
R403, R411, R418: 24k; R_0603_1608Metric
R404, R405, R413, R414, R420, R421: 100m; R_1206_3216Metric
RV401, RV402, RV403: 10k; Potentiometer_Bourns_3314J_Vertical
SW301, SW302: SW_Push; SW_Push_1P1T_XKB_TS-1187A
U201: TP6841S6; SOT-23-6
U202: AMS1117; SOT-223-3_TabPin2
U301: ESP32-C6-MINI-1; ESP32-C6-MINI-1U
U401, U402, U403: A4988; QFN-28-1EP_5x5mm_P0.5mm_EP3.25x3.25mm_ThermalVias

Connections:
+3.3V: C206.1, C301.2, C302.1, J303.1, J304.2, J305.2, R301.1, R304.1, U202.2 (VO), U301.3 (3V3)
+5V: C204.1, C205.1, C401.2, C402.1, C409.2, C410.1, C417.2, C418.1, D303.1 (K), J202.1, L201.2, R201.2, R203.1, R401.2, R406.1, R407.2, R408.1, R409.1, R412.2, R415.1, R416.1, R419.1, R422.1, R423.1, R424.1, U202.3 (VI), U401.9 (MS1), U401.10 (MS2), U401.11 (MS3), U401.15 (VDD), U402.15 (VDD), U403.15 (VDD)
+24V: C403.2, C405.2, C406.2, C407.1, C411.2, C413.2, C414.2, C415.1, C419.2, C421.2, C422.2, C423.1, J203.2, R402.1, R410.1, R417.1, U401.22 (VBB1), U401.28 (VBB2), U402.22 (VBB1), U402.28 (VBB2), U403.22 (VBB1), U403.28 (VBB2)
/Microcontroller/+VBUS: D303.2 (A), D304.2 (A), J302.1 (VBUS)
/Microcontroller/AGITATION_SWITCH: J303.2, U301.20 (IO15)
/Microcontroller/BOOT: C305.2, SW302.2, U301.23 (IO9)
/Microcontroller/EN: C303.2, C304.1, R301.2, SW301.2, U301.8 (EN)
/Microcontroller/HORIZONTAL_SWITCH: J305.1, U301.16 (IO7)
/Microcontroller/IO8: R304.2, U301.22 (IO8)
/Microcontroller/RXD: J301.2, R302.2
/Microcontroller/RXD0: R303.1, U301.30 (RXD0)
/Microcontroller/TXD: J301.3, R303.2
/Microcontroller/TXD0: R302.1, U301.31 (TXD0)
/Microcontroller/USB_D+: D302.2 (A), J302.3 (D+), U301.18 (IO13)
/Microcontroller/USB_D-: D301.2 (A), J302.2 (D-), U301.17 (IO12)
/Microcontroller/VERTICAL_SWITCH: J304.1, U301.15 (IO6)
/Power Supply/BUCK_BST: C201.2, U201.1 (BST)
/Power Supply/BUCK_EN: R202.2, U201.4 (EN)
/Power Supply/BUCK_FB: R203.2, R204.2, U201.3 (FB)
/Power Supply/BUCK_SW: C201.1, L201.1, U201.6 (SW)
/Power Supply/DIGITAL_POWER_+24V: C202.1, C203.2, J201.2, J206.1, J207.1, R202.1, U201.5 (VIN)
/Stepper Drivers/AGITATE_1A: J401.2, U401.24 (OUT1A)
/Stepper Drivers/AGITATE_1B: J401.1, U401.21 (OUT1B)
/Stepper Drivers/AGITATE_2A: J401.3, U401.26 (OUT2A)
/Stepper Drivers/AGITATE_2B: J401.4, U401.1 (OUT2B)
/Stepper Drivers/A_CP1: C408.1, U401.4 (CP1)
/Stepper Drivers/A_CP2: C408.2, U401.5 (CP2)
/Stepper Drivers/A_FLYBACK: D401.1 (K), R402.2
/Stepper Drivers/A_POT_IN: R401.1, RV401.1
/Stepper Drivers/A_RESET: R406.2, U401.12 (~RESET)
/Stepper Drivers/A_ROSC: R403.2, U401.13 (ROSC)
/Stepper Drivers/A_SENSE1: R404.1, U401.23 (SENSE1)
/Stepper Drivers/A_SENSE2: R405.1, U401.27 (SENSE2)
/Stepper Drivers/A_SLEEP: R408.2, U401.14 (~SLEEP)
/Stepper Drivers/A_VCP: C403.1, U401.6 (VCP)
/Stepper Drivers/A_VREF: RV401.2, U401.17 (VREF)
/Stepper Drivers/A_VREG: C404.1, U401.8 (VREG)
/Stepper Drivers/HORIZONTAL_1A: J402.2, U402.24 (OUT1A)
/Stepper Drivers/HORIZONTAL_1B: J402.1, U402.21 (OUT1B)
/Stepper Drivers/HORIZONTAL_2A: J402.3, U402.26 (OUT2A)
/Stepper Drivers/HORIZONTAL_2B: J402.4, U402.1 (OUT2B)
/Stepper Drivers/H_CP1: C416.1, U402.4 (CP1)
/Stepper Drivers/H_CP2: C416.2, U402.5 (CP2)
/Stepper Drivers/H_FLYBACK: D402.1 (K), R410.2
/Stepper Drivers/H_POT_IN: R407.1, RV402.1
/Stepper Drivers/H_RESET: R415.2, U402.12 (~RESET)
/Stepper Drivers/H_ROSC: R411.2, U402.13 (ROSC)
/Stepper Drivers/H_SENSE1: R413.1, U402.23 (SENSE1)
/Stepper Drivers/H_SENSE2: R414.1, U402.27 (SENSE2)
/Stepper Drivers/H_SLEEP: R416.2, U402.14 (~SLEEP)
/Stepper Drivers/H_VCP: C411.1, U402.6 (VCP)
/Stepper Drivers/H_VREF: RV402.2, U402.17 (VREF)
/Stepper Drivers/H_VREG: C412.1, U402.8 (VREG)
/Stepper Drivers/VERTICAL_1A: J403.2, U403.24 (OUT1A)
/Stepper Drivers/VERTICAL_1B: J403.1, U403.21 (OUT1B)
/Stepper Drivers/VERTICAL_2A: J403.3, U403.26 (OUT2A)
/Stepper Drivers/VERTICAL_2B: J403.4, U403.1 (OUT2B)
/Stepper Drivers/V_CP1: C424.1, U403.4 (CP1)
/Stepper Drivers/V_CP2: C424.2, U403.5 (CP2)
/Stepper Drivers/V_FLYBACK: D403.1 (K), R417.2
/Stepper Drivers/V_POT_IN: R412.1, RV403.1
/Stepper Drivers/V_RESET: R422.2, U403.12 (~RESET)
/Stepper Drivers/V_ROSC: R418.2, U403.13 (ROSC)
/Stepper Drivers/V_SENSE1: R420.1, U403.23 (SENSE1)
/Stepper Drivers/V_SENSE2: R421.1, U403.27 (SENSE2)
/Stepper Drivers/V_SLEEP: R423.2, U403.14 (~SLEEP)
/Stepper Drivers/V_VCP: C419.1, U403.6 (VCP)
/Stepper Drivers/V_VREF: RV403.2, U403.17 (VREF)
/Stepper Drivers/V_VREG: C420.1, U403.8 (VREG)
AGITATION_DIR: U301.24 (IO18), U401.19 (DIR)
AGITATION_STEP: U301.25 (IO19), U401.16 (STEP)
DRIVER_ENABLE: R409.2, R419.2, R424.2, U301.28 (IO22), U401.2 (~ENABLE), U402.2 (~ENABLE), U403.2 (~ENABLE)
GND: C202.2, C203.1, C204.2, C205.2, C206.2, C301.1, C302.2, C303.1, C304.2, C305.1, C401.1, C402.2, C404.2, C405.1, C406.1, C407.2, C409.1, C410.2, C412.2, C413.1, C414.1, C415.2, C417.1, C418.2, C420.2, C421.1, C422.1, C423.2, D201.1 (K), D301.1 (K), D302.1 (K), D304.1 (K), D401.2 (A), D402.2 (A), D403.2 (A), H201.1, H202.1, H203.1, H204.1, J201.1, J202.2, J203.1, J206.2, J207.2, J302.5 (GND), R204.1, R403.1, R404.2, R405.2, R411.1, R413.2, R414.2, R418.1, R420.2, R421.2, RV401.3, RV402.3, RV403.3, SW301.1, SW302.1, U201.2 (GND), U202.1 (ADJ), U301.1 (GND), U301.2 (GND), U301.11 (GND), U301.14 (GND), U301.36 (GND), U301.37 (GND), U301.38 (GND), U301.39 (GND), U301.40 (GND), U301.41 (GND), U301.42 (GND), U301.43 (GND), U301.44 (GND), U301.45 (GND), U301.46 (GND), U301.47 (GND), U301.48 (GND), U301.49 (GND), U301.50 (GND), U301.51 (GND), U301.52 (GND), U301.53 (GND), U401.3 (GND), U401.18 (GND), U401.29 (GND), U402.3 (GND), U402.18 (GND), U402.29 (GND), U403.3 (GND), U403.18 (GND), U403.29 (GND)
HORIZONTAL_DIR: U301.9 (IO4), U402.19 (DIR)
HORIZONTAL_STEP: U301.10 (IO5), U402.16 (STEP)
unnamed: D201.2 (A), R201.1
VERTICAL_DIR: U301.6 (IO3), U403.19 (DIR)
VERTICAL_STEP: U301.5 (IO2), U403.16 (STEP)

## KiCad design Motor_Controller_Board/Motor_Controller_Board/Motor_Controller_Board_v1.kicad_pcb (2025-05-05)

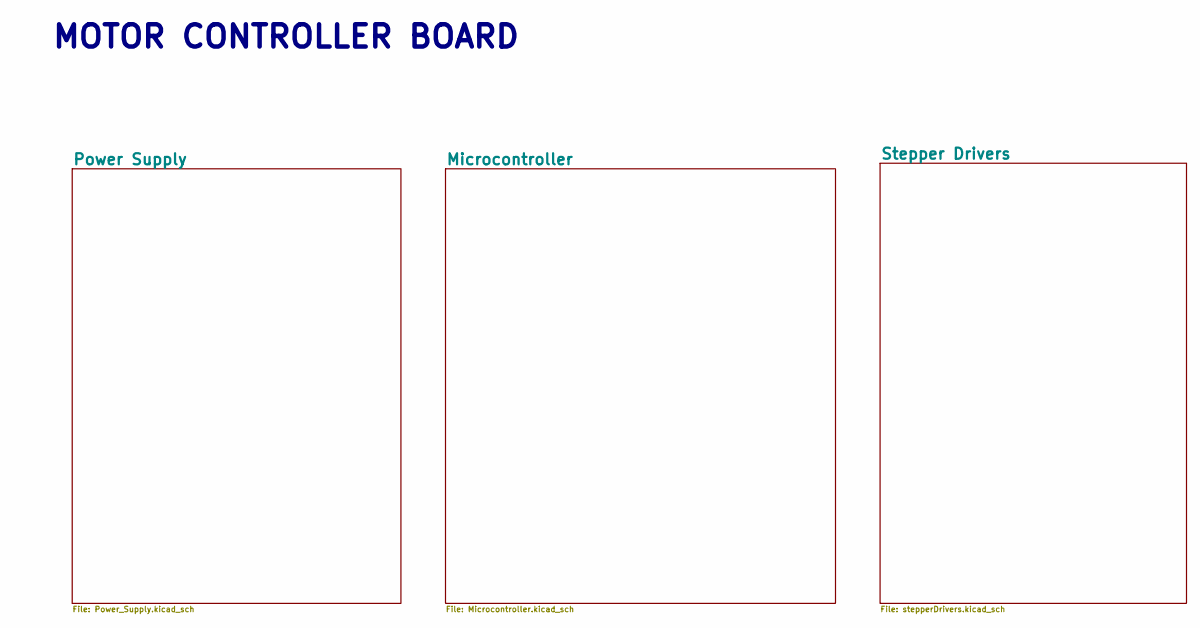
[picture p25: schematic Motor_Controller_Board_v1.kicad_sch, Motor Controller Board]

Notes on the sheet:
MOTOR CONTROLLER BOARD

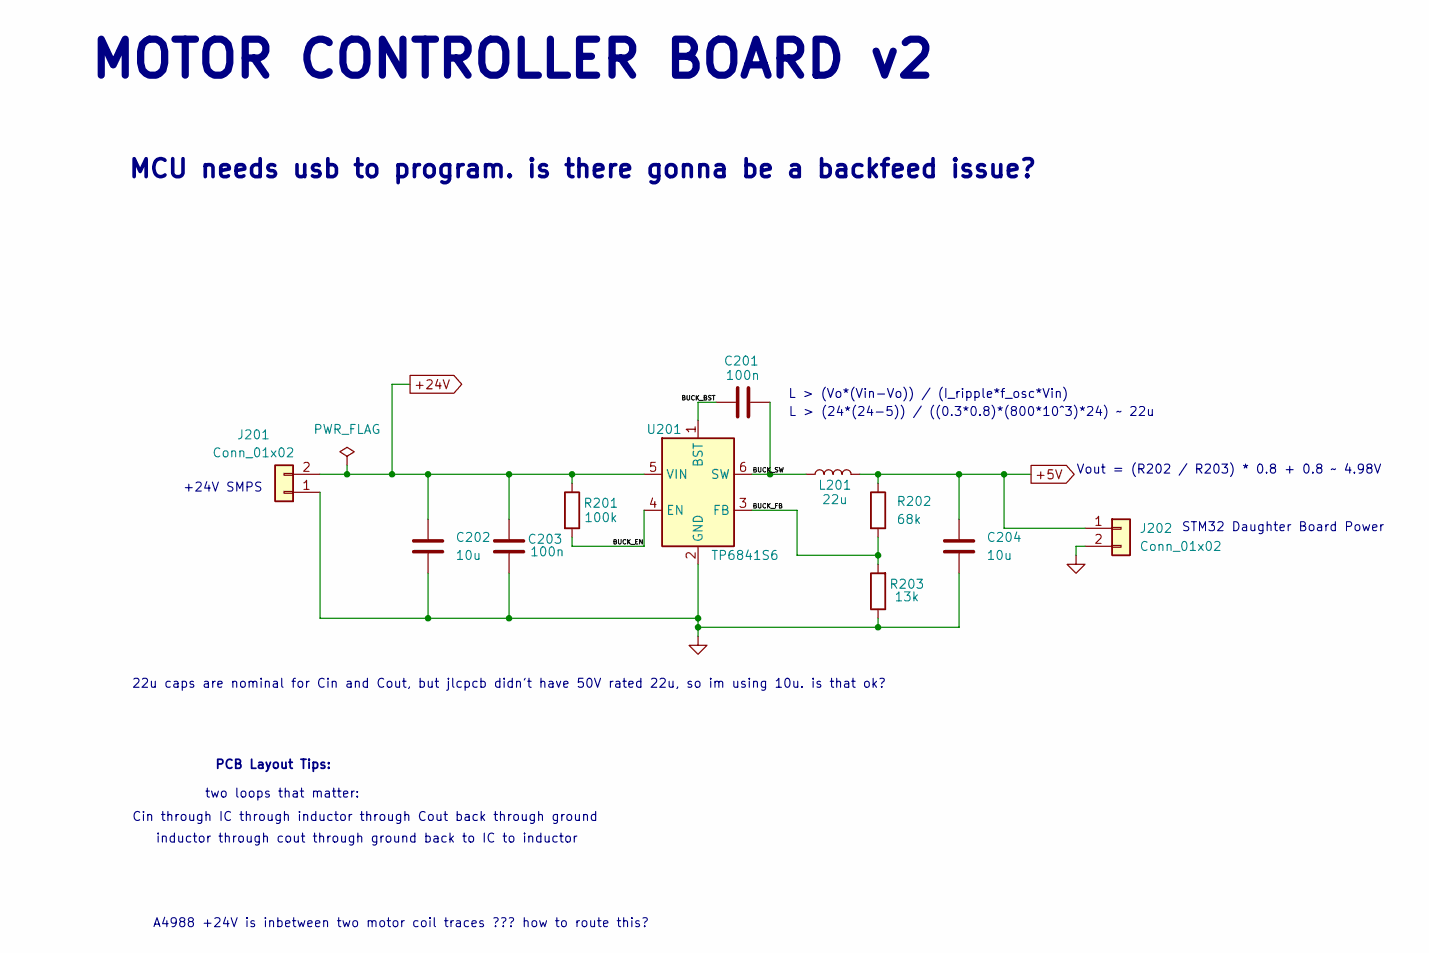
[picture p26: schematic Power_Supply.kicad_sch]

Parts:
C201, C203: 100n; C_0603_1608Metric; MPN CC0603KRX7R9BB104; LCSC Part Number C14663
C202, C204: 10u; C_0805_2012Metric; MPN GRM21BR61H106KE43L; LCSC Part Number C440198
J201: Conn_01x02; TerminalBlock_bornier-2_P5.08mm
J202: Conn_01x02; PinHeader_1x02_P2.54mm_Vertical
L201: 22u; L_10.4x10.4_H4.8; MPN SMDRH105R-220MT; LCSC Part Number C10165
R201: 100k; R_0603_1608Metric; MPN 0603WAF1003T5E; LCSC Part Number C25803
R202: 68k; R_0603_1608Metric; MPN 0603WAF6802T5E; LCSC Part Number C23231
R203: 13k; R_0603_1608Metric; MPN 0603WAF1302T5E; LCSC Part Number C22797
U201: TP6841S6; SOT-23-6; MPN TP6841S6-A; LCSC Part Number C2844924

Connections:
+5V: C204.1, J202.1, L201.2, R202.1; also elsewhere on the board
+24V: C202.1, C203.2, J201.2, R201.1, U201.5 (VIN); also elsewhere on the board
/Power Supply/BUCK_BST: C201.2, U201.1 (BST)
/Power Supply/BUCK_EN: R201.2, U201.4 (EN)
/Power Supply/BUCK_FB: R202.2, R203.2, U201.3 (FB)
/Power Supply/BUCK_SW: C201.1, L201.1, U201.6 (SW)
GND: C202.2, C203.1, C204.2, J201.1, J202.2, R203.1, U201.2 (GND); also elsewhere on the board

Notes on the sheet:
A4988 +24V is inbetween two motor coil traces ??? how to route this?
+24V SMPS
L > (24*(24-5)) / ((0.3*0.8)*(800*10^3)*24) ~ 22u
PCB Layout Tips:
two loops that matter:
Vout = (R202 / R203) * 0.8 + 0.8 ~ 4.98V
22u caps are nominal for Cin and Cout, but jlcpcb didn't have 50V rated 22u, so im using 10u. is that ok?
MCU needs usb to program. is there gonna be a backfeed issue?
MOTOR CONTROLLER BOARD v2
STM32 Daughter Board Power
inductor through cout through ground back to IC to inductor
L > (Vo*(Vin-Vo)) / (I_ripple*f_osc*Vin)
Cin through IC through inductor through Cout back through ground

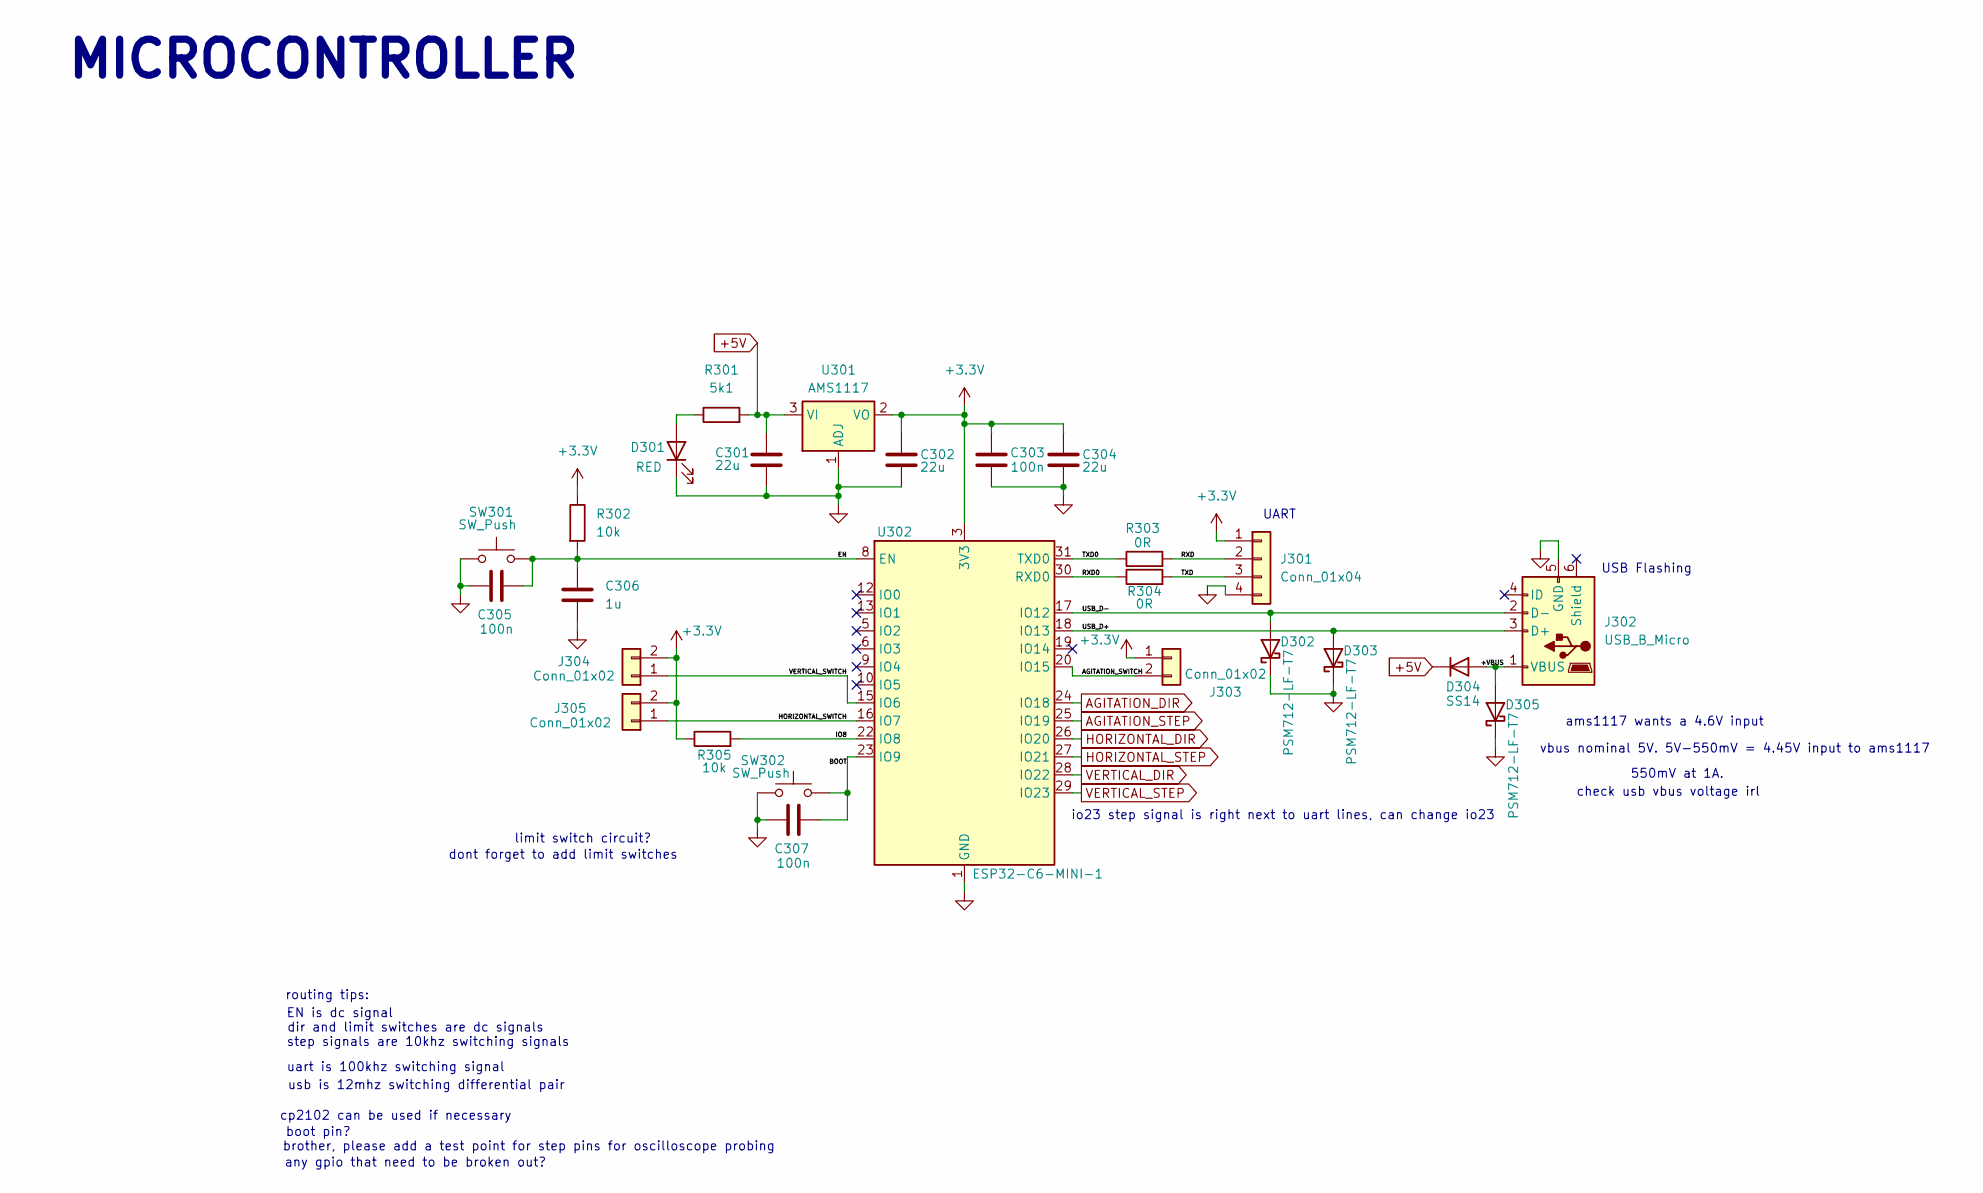
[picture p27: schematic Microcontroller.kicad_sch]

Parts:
C301, C302, C304: 22u; C_0603_1608Metric; MPN CL21A226MAQNNNE; LCSC Part Number C45783
C303, C305, C307: 100n; C_0402_1005Metric; MPN CL05B104KO5NNNC; LCSC Part Number C1525
C306: 1u; C_0402_1005Metric; MPN CL05A105KA5NQNC; LCSC Part Number C52923
D301: RED; LED_0603_1608Metric; MPN KT-0603R; LCSC Part Number C2286
D302, D303, D305: PSM712-LF-T7; SOT-23; MPN PSM712-LF-T7; LCSC Part Number C32677
D304: SS14; D_SMA; MPN SS14; LCSC Part Number C2480
J301: Conn_01x04; PinHeader_1x04_P2.54mm_Vertical
J302: USB_B_Micro; USB_Micro-B_Molex-105017-0001; MPN MicroXNJ; LCSC Part Number C404969
J303, J304, J305: Conn_01x02; PinHeader_1x02_P2.54mm_Vertical
R301: 5k1; R_0603_1608Metric; MPN 0603WAF5101T5E; LCSC Part Number C23186
R302, R305: 10k; R_0603_1608Metric; MPN 0603WAF1002T5E; LCSC Part Number C25804
R303, R304: 0R; R_0603_1608Metric; MPN 0603WAF0000T5E; LCSC Part Number C21189
SW301, SW302: SW_Push; SW_Push_1P1T_XKB_TS-1187A; MPN TS-1187A-B-A-B; LCSC Part Number C318884
U301: AMS1117; SOT-223-3_TabPin2; MPN AMS1117-3.3; LCSC Part Number C6186
U302: ESP32-C6-MINI-1; ESP32-C6-MINI-1U; MPN ESP32-C6-MINI-1U-H4; LCSC Part Number C20627095

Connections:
+3.3V: C302.1, C303.2, C304.1, J301.1, J303.1, J304.2, J305.2, R302.1, R305.1, U301.2 (VO), U302.3 (3V3)
+5V: C301.1, D304.1 (K), R301.2, U301.3 (VI); also elsewhere on the board
/Microcontroller/+VBUS: D304.2 (A), D305.2 (A), J302.1 (VBUS)
/Microcontroller/AGITATION_SWITCH: J303.2, U302.20 (IO15)
/Microcontroller/BOOT: C307.2, SW302.2, U302.23 (IO9)
/Microcontroller/EN: C305.2, C306.1, R302.2, SW301.2, U302.8 (EN)
/Microcontroller/HORIZONTAL_SWITCH: J305.1, U302.16 (IO7)
/Microcontroller/IO8: R305.2, U302.22 (IO8)
/Microcontroller/RXD: J301.2, R303.2
/Microcontroller/RXD0: R304.1, U302.30 (RXD0)
/Microcontroller/TXD: J301.3, R304.2
/Microcontroller/TXD0: R303.1, U302.31 (TXD0)
/Microcontroller/USB_D+: D303.2 (A), J302.3 (D+), U302.18 (IO13)
/Microcontroller/USB_D-: D302.2 (A), J302.2 (D-), U302.17 (IO12)
/Microcontroller/VERTICAL_SWITCH: J304.1, U302.15 (IO6)
AGITATION_DIR: U302.24 (IO18); also elsewhere on the board
AGITATION_STEP: U302.25 (IO19); also elsewhere on the board
GND: C301.2, C302.2, C303.1, C304.2, C305.1, C306.2, C307.1, D301.1 (K), D302.1 (K), D303.1 (K), D305.1 (K), J301.4, J302.5 (GND), SW301.1, SW302.1, U301.1 (ADJ), U302.1 (GND), U302.2 (GND), U302.11 (GND), U302.14 (GND), U302.36 (GND), U302.37 (GND), U302.38 (GND), U302.39 (GND), U302.40 (GND), U302.41 (GND), U302.42 (GND), U302.43 (GND), U302.44 (GND), U302.45 (GND), U302.46 (GND), U302.47 (GND), U302.48 (GND), U302.49 (GND), U302.50 (GND), U302.51 (GND), U302.52 (GND), U302.53 (GND); also elsewhere on the board
HORIZONTAL_DIR: U302.26 (IO20); also elsewhere on the board
HORIZONTAL_STEP: U302.27 (IO21); also elsewhere on the board
unnamed: D301.2 (A), R301.1
VERTICAL_DIR: U302.28 (IO22); also elsewhere on the board
VERTICAL_STEP: U302.29 (IO23); also elsewhere on the board

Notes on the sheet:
MICROCONTROLLER
check usb vbus voltage irl
any gpio that need to be broken out?
dont forget to add limit switches
UART
dir and limit switches are dc signals
cp2102 can be used if necessary
vbus nominal 5V. 5V-550mV = 4.45V input to ams1117
USB Flashing
routing tips:
550mV at 1A.
io23 step signal is right next to uart lines, can change io23
EN is dc signal
step signals are 10khz switching signals
boot pin?
brother, please add a test point for step pins for oscilloscope probing
limit switch circuit?
ams1117 wants a 4.6V input
usb is 12mhz switching differential pair
uart is 100khz switching signal

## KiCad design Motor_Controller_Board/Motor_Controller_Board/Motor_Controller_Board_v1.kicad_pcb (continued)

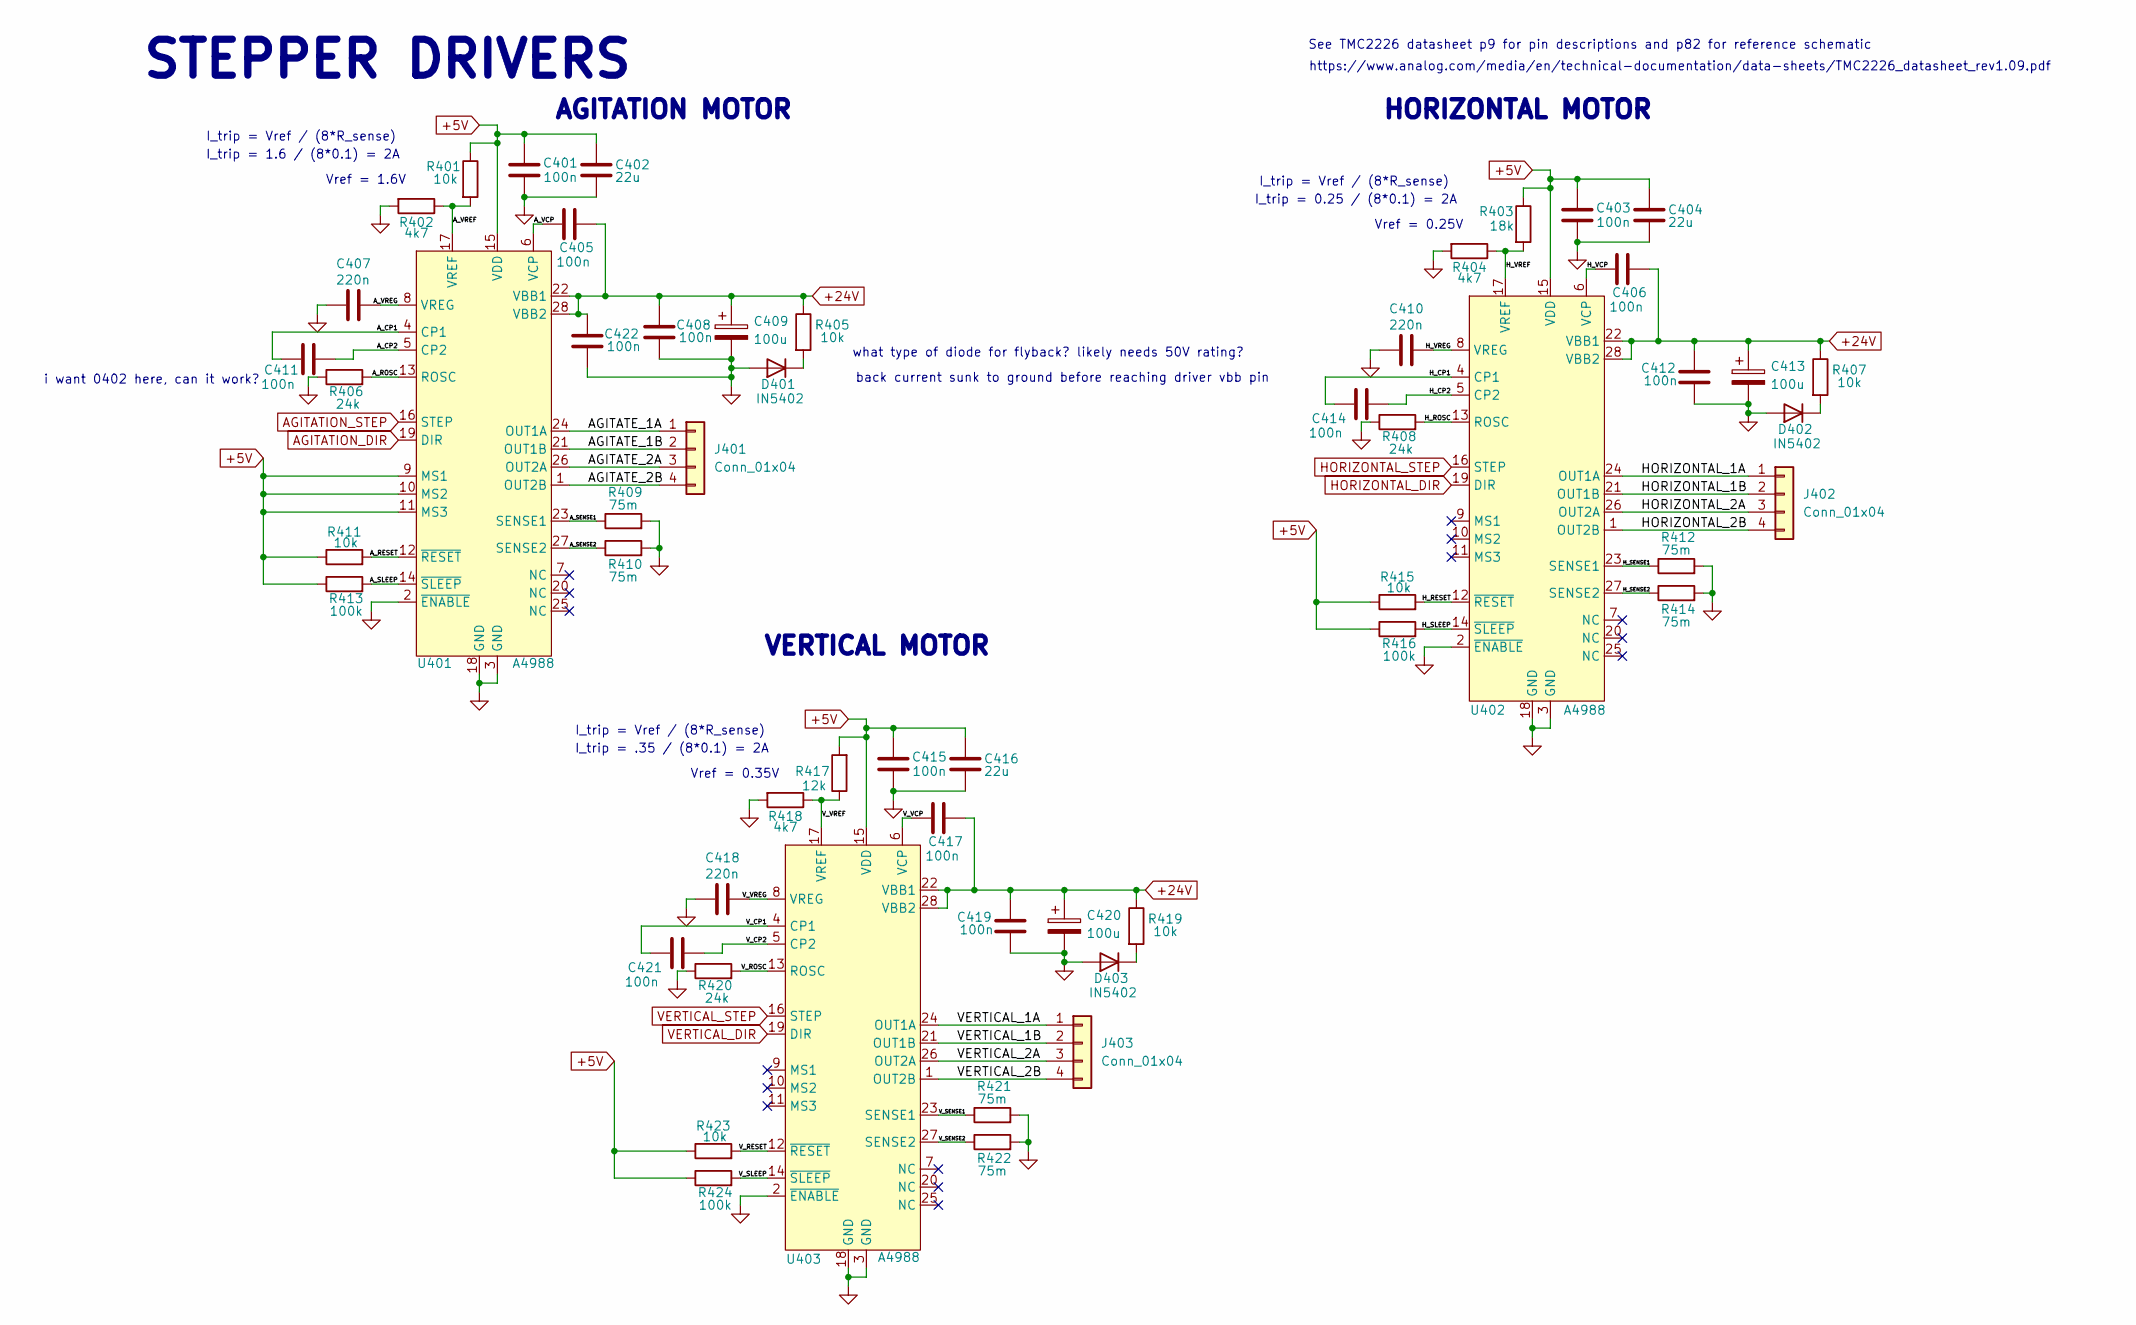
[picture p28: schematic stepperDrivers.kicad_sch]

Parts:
C401, C403, C415: 100n; C_0402_1005Metric; MPN CL05B104KO5NNNC; LCSC Part Number C1525
C402, C404, C416: 22u; C_0603_1608Metric; MPN CL21A226MAQNNNE; LCSC Part Number C45783
C405, C406, C408, C411, C412, C414, C417, C419, C421, C422: 100n; C_0603_1608Metric; MPN CC0603KRX7R9BB104; LCSC Part Number C14663
C407, C410, C418: 220n; C_0805_2012Metric; MPN CL21B224KBFNNNE; LCSC Part Number C5378
C409, C413, C420: 100u; CP_Radial_D16.0mm_P7.50mm
D401, D402, D403: IN5402; D_DO-27_P15.24mm_Horizontal
J401, J402, J403: Conn_01x04; TerminalBlock_bornier-4_P5.08mm
R401, R405, R407, R411, R415, R419, R423: 10k; R_0603_1608Metric; MPN 0603WAF1002T5E; LCSC Part Number C25804
R402, R404, R418: 4k7; R_0603_1608Metric; MPN 0603WAF4701T5E; LCSC Part Number C23162
R403: 18k; R_0603_1608Metric; MPN 0603WAF1802T5E; LCSC Part Number C25810
R406, R408, R420: 24k; R_0603_1608Metric; MPN 0603WAF2402T5E; LCSC Part Number C23352
R409, R410, R412, R414, R421, R422: 75m; R_1206_3216Metric; MPN CR1206FR075P05R; LCSC Part Number C149663
R413, R416, R424: 100k; R_0603_1608Metric; MPN 0603WAF1003T5E; LCSC Part Number C25803
R417: 12k; R_0603_1608Metric; MPN 0603WAF1202T5E; LCSC Part Number C22790
U401, U402, U403: A4988; QFN-28-1EP_5x5mm_P0.5mm_EP3.25x3.25mm_ThermalVias; MPN A4988SETTR-T; LCSC Part Number C38437

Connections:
+5V: C401.2, C402.1, C403.2, C404.1, C415.2, C416.1, R401.1, R403.1, R411.1, R413.1, R415.1, R416.1, R417.2, R423.1, R424.1, U401.9 (MS1), U401.10 (MS2), U401.11 (MS3), U401.15 (VDD), U402.15 (VDD), U403.15 (VDD); also elsewhere on the board
+24V: C405.2, C406.2, C408.2, C409.1, C412.2, C413.1, C417.2, C419.2, C420.1, C422.2, R405.1, R407.1, R419.1, U401.22 (VBB1), U401.28 (VBB2), U402.22 (VBB1), U402.28 (VBB2), U403.22 (VBB1), U403.28 (VBB2); also elsewhere on the board
/Stepper Drivers/AGITATE_1A: J401.1, U401.24 (OUT1A)
/Stepper Drivers/AGITATE_1B: J401.2, U401.21 (OUT1B)
/Stepper Drivers/AGITATE_2A: J401.3, U401.26 (OUT2A)
/Stepper Drivers/AGITATE_2B: J401.4, U401.1 (OUT2B)
/Stepper Drivers/A_CP1: C411.1, U401.4 (CP1)
/Stepper Drivers/A_CP2: C411.2, U401.5 (CP2)
/Stepper Drivers/A_FLYBACK: D401.1 (K), R405.2
/Stepper Drivers/A_RESET: R411.2, U401.12 (~RESET)
/Stepper Drivers/A_ROSC: R406.2, U401.13 (ROSC)
/Stepper Drivers/A_SENSE1: R409.1, U401.23 (SENSE1)
/Stepper Drivers/A_SENSE2: R410.1, U401.27 (SENSE2)
/Stepper Drivers/A_SLEEP: R413.2, U401.14 (~SLEEP)
/Stepper Drivers/A_VCP: C405.1, U401.6 (VCP)
/Stepper Drivers/A_VREF: R401.2, R402.1, U401.17 (VREF)
/Stepper Drivers/A_VREG: C407.1, U401.8 (VREG)
/Stepper Drivers/HORIZONTAL_1A: J402.1, U402.24 (OUT1A)
/Stepper Drivers/HORIZONTAL_1B: J402.2, U402.21 (OUT1B)
/Stepper Drivers/HORIZONTAL_2A: J402.3, U402.26 (OUT2A)
/Stepper Drivers/HORIZONTAL_2B: J402.4, U402.1 (OUT2B)
/Stepper Drivers/H_CP1: C414.1, U402.4 (CP1)
/Stepper Drivers/H_CP2: C414.2, U402.5 (CP2)
/Stepper Drivers/H_FLYBACK: D402.1 (K), R407.2
/Stepper Drivers/H_RESET: R415.2, U402.12 (~RESET)
/Stepper Drivers/H_ROSC: R408.2, U402.13 (ROSC)
/Stepper Drivers/H_SENSE1: R412.1, U402.23 (SENSE1)
/Stepper Drivers/H_SENSE2: R414.1, U402.27 (SENSE2)
/Stepper Drivers/H_SLEEP: R416.2, U402.14 (~SLEEP)
/Stepper Drivers/H_VCP: C406.1, U402.6 (VCP)
/Stepper Drivers/H_VREF: R403.2, R404.1, U402.17 (VREF)
/Stepper Drivers/H_VREG: C410.1, U402.8 (VREG)
/Stepper Drivers/VERTICAL_1A: J403.1, U403.24 (OUT1A)
/Stepper Drivers/VERTICAL_1B: J403.2, U403.21 (OUT1B)
/Stepper Drivers/VERTICAL_2A: J403.3, U403.26 (OUT2A)
/Stepper Drivers/VERTICAL_2B: J403.4, U403.1 (OUT2B)
/Stepper Drivers/V_CP1: C421.1, U403.4 (CP1)
/Stepper Drivers/V_CP2: C421.2, U403.5 (CP2)
/Stepper Drivers/V_FLYBACK: D403.1 (K), R419.2
/Stepper Drivers/V_RESET: R423.2, U403.12 (~RESET)
/Stepper Drivers/V_ROSC: R420.2, U403.13 (ROSC)
/Stepper Drivers/V_SENSE1: R421.1, U403.23 (SENSE1)
/Stepper Drivers/V_SENSE2: R422.1, U403.27 (SENSE2)
/Stepper Drivers/V_SLEEP: R424.2, U403.14 (~SLEEP)
/Stepper Drivers/V_VCP: C417.1, U403.6 (VCP)
/Stepper Drivers/V_VREF: R417.1, R418.1, U403.17 (VREF)
/Stepper Drivers/V_VREG: C418.1, U403.8 (VREG)
AGITATION_DIR: U401.19 (DIR); also elsewhere on the board
AGITATION_STEP: U401.16 (STEP); also elsewhere on the board
GND: C401.1, C402.2, C403.1, C404.2, C407.2, C408.1, C409.2, C410.2, C412.1, C413.2, C415.1, C416.2, C418.2, C419.1, C420.2, C422.1, D401.2 (A), D402.2 (A), D403.2 (A), R402.2, R404.2, R406.1, R408.1, R409.2, R410.2, R412.2, R414.2, R418.2, R420.1, R421.2, R422.2, U401.2 (~ENABLE), U401.3 (GND), U401.18 (GND), U401.29 (GND), U402.2 (~ENABLE), U402.3 (GND), U402.18 (GND), U402.29 (GND), U403.2 (~ENABLE), U403.3 (GND), U403.18 (GND), U403.29 (GND); also elsewhere on the board
HORIZONTAL_DIR: U402.19 (DIR); also elsewhere on the board
HORIZONTAL_STEP: U402.16 (STEP); also elsewhere on the board
VERTICAL_DIR: U403.19 (DIR); also elsewhere on the board
VERTICAL_STEP: U403.16 (STEP); also elsewhere on the board

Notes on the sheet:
I_trip = 0.25 / (8*0.1) = 2A
I_trip = Vref / (8*R_sense)
i want 0402 here, can it work?
Vref = 1.6V
VERTICAL MOTOR
back current sunk to ground before reaching driver vbb pin
Vref = 0.35V
I_trip = .35 / (8*0.1) = 2A
AGITATION MOTOR
STEPPER DRIVERS
See TMC2226 datasheet p9 for pin descriptions and p82 for reference schematic
Vref = 0.25V
HORIZONTAL MOTOR
https://www.analog.com/media/en/technical-documentation/data-sheets/TMC2226_datasheet_rev1.09.pdf
I_trip = 1.6 / (8*0.1) = 2A
what type of diode for flyback? likely needs 50V rating?

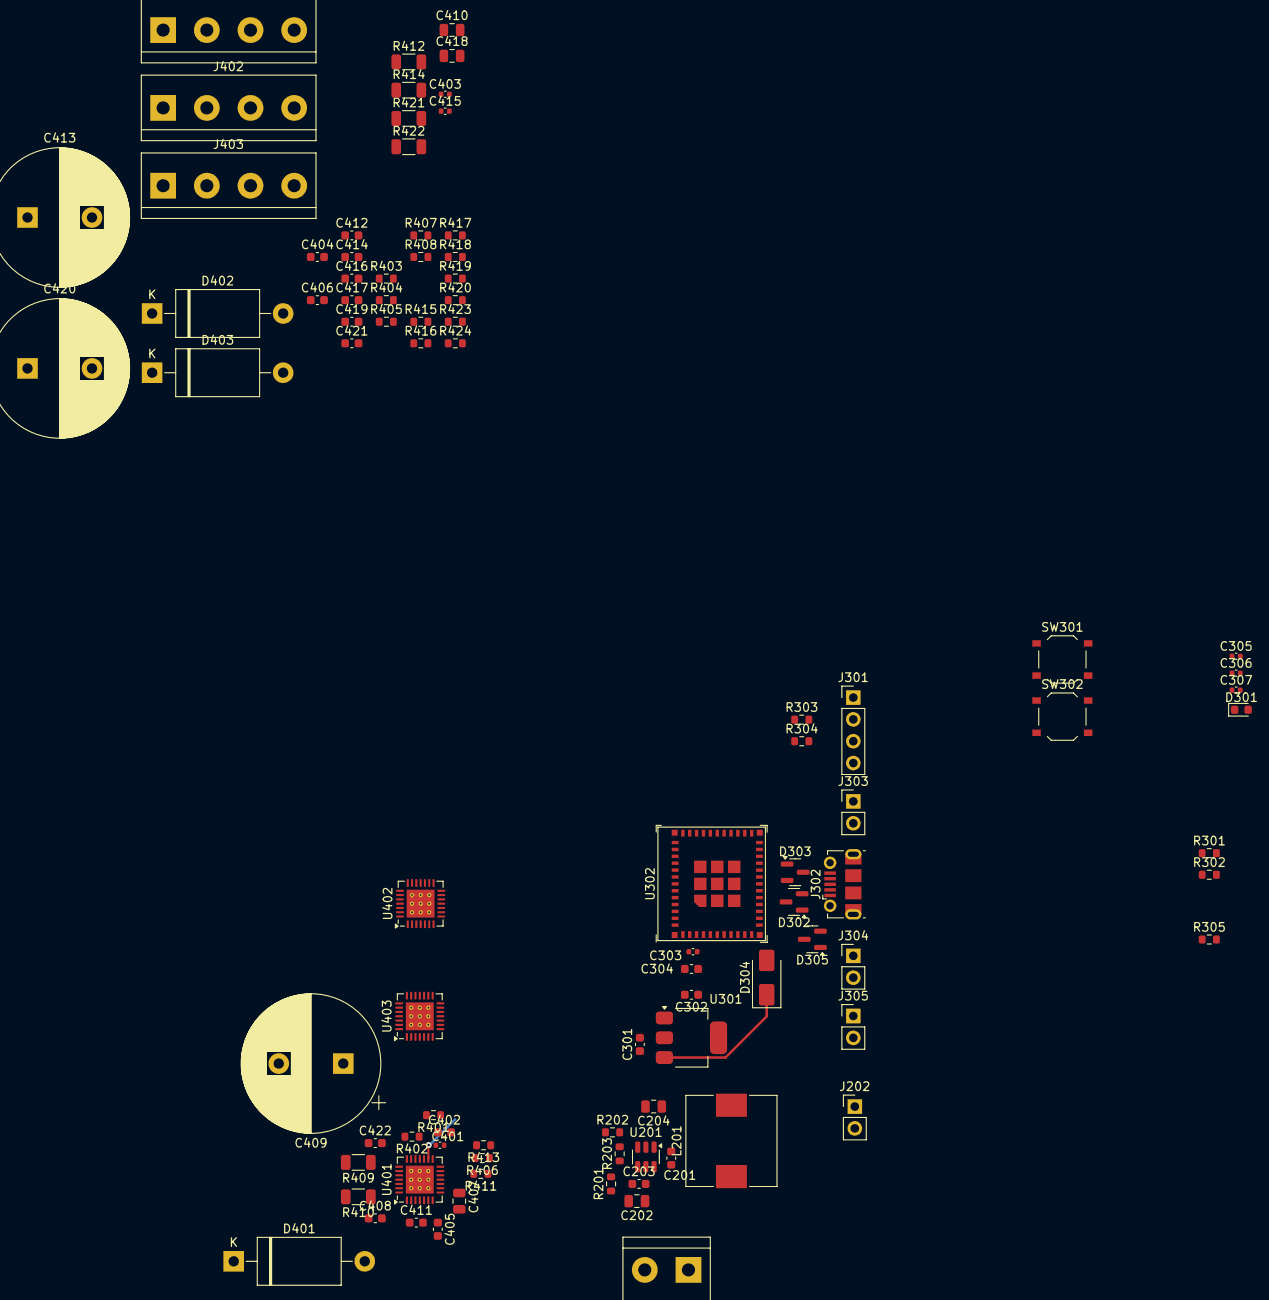
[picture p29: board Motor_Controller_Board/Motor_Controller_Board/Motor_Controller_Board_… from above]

Board: 2 copper layers, 92 parts (0 on the bottom side), 73 nets.

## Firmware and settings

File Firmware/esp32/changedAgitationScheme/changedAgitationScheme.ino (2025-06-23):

/************
* 5/22/25
* Gregory Ziegler + Dorjee Tenzing
* Overview:
* This is the firmware for the ASATS Motor Controller Board. 
* The goal of this firmware is to automate the blood testing procedures for the ASATS device.

* This program has a state machine with describing two main types of behavior:
* - Receiving protocol instructions from an STM32 microcontroller's touchscreen through UART
* - Parsing the UART data and to perform either agitation or magnetization
*************/

//note: ALWAYS AUTOHOME AGITATION MOTOR BEFORE EXCUTING A FUNCTION

/*************** library inclusions and macro definitions***************/
#include <HardwareSerial.h>
#include <ezButton.h>
#include <AccelStepper.h>

HardwareSerial MySerial(0);  // Use UART0

#define MAX_LINE_LENGTH 32
#define MAX_LINES 100
#define PWM_RESOLUTION 8
#define LIMIT_SWITCH_DEBOUNCE_TIME 100

//experimental locations on the ASATS machine
#define HORIZONTAL_ABOVE_TEST_TRAY_LOCATION 52 //this is slightly inaccurate becasue of limit switch detection having lag
#define VERTICAL_ABOVE_TEST_TRAY_LOCATION 38  //43 -> 37 on 5/28/25
#define HEIGHT_OF_TEST_TUBE 38                //38 -> 44 on 5/28/25

/******************* PIN DEFINITIONS **************/

//agitation motor
const int AGITATION_MOTOR_STEP = 19;
const int AGITATION_MOTOR_DIR = 18;
const int AGITATION_MOTOR_STEP_CHANNEL = 2;

//horizontal motor
const int MOTOR_X_STEP = 5;
const int MOTOR_X_DIR = 4;
const int MOTOR_X_STEP_CHANNEL = 4;

//vertical motor
const int MOTOR_Y_STEP = 2;  //
const int MOTOR_Y_DIR = 3;   //
const int MOTOR_Y_STEP_CHANNEL = 3;

//limit switches
const int AGITATION_SWITCH = 15;
const int VERTICAL_SWITCH = 6;
const int HORIZONTAL_SWITCH = 7;
ezButton limitSwitchY(VERTICAL_SWITCH);           // create ezButton object that attach to ESP32 pin GPIO6
ezButton limitSwitchX(HORIZONTAL_SWITCH);         // create ezButton object that attach to ESP32 pin GPIO7
ezButton limitSwitchAgitation(AGITATION_SWITCH);  // create ezButton object that attach to ESP32 pin GPIO15

//motor enable
const int MOTOR_ENABLE = 22;

//accelstepper instantiation
AccelStepper stepper(AccelStepper::DRIVER, AGITATION_MOTOR_STEP, AGITATION_MOTOR_DIR);

/******************* STATE MACHINE SETUP *****************/
typedef enum {
  waitingState,
  runState
} operationState;

operationState currentState = waitingState;

/****************** INITIALIZE FUNCTIONS **************/
uint8_t autoHome(void);
uint8_t agitateMotors(uint16_t agitateSpeed, uint8_t agitateDuration, uint8_t mixPosition, uint8_t mixScope, uint8_t pauseDuration, uint8_t repeat);
uint8_t pauseMotors(uint8_t pauseDuration);
uint8_t moveSample(uint8_t initialSurfaceTime, uint8_t speed, uint8_t stopAtSequences, uint8_t sequencePauseTime);

/************** INITALIZE VARIABLES ****************/

char tempBuffer[MAX_LINES][MAX_LINE_LENGTH] = { { '\0' } };  // Initialize the tempBuffer with nulls ('\0')
uint8_t startFlag = 0;
uint8_t i = 0;
uint8_t j = 0;
uint8_t finishFlag = 1;


void setup() {
  /*********** Set up UART and GPIO ***********/

  //motor enable
  pinMode(MOTOR_ENABLE, OUTPUT);
  digitalWrite(MOTOR_ENABLE, 1);  //keep motors off until touchscreen enables them

  //hardware UART0
  Serial.begin(115200);
  MySerial.begin(115200);

  //limit switch debouncing
  limitSwitchAgitation.setDebounceTime(LIMIT_SWITCH_DEBOUNCE_TIME);  // set debounce time of limit switch to 50 milliseconds
  limitSwitchX.setDebounceTime(LIMIT_SWITCH_DEBOUNCE_TIME);
  limitSwitchY.setDebounceTime(LIMIT_SWITCH_DEBOUNCE_TIME);

  //limit switches are pulled down. when pressed, they connect to vcc
  pinMode(HORIZONTAL_SWITCH, INPUT_PULLDOWN);
  pinMode(VERTICAL_SWITCH, INPUT_PULLDOWN);
  pinMode(AGITATION_SWITCH, INPUT_PULLDOWN);

  //motor direction pins are digital outputs
  pinMode(AGITATION_MOTOR_DIR, OUTPUT);
  pinMode(MOTOR_Y_DIR, OUTPUT);
  pinMode(MOTOR_X_DIR, OUTPUT);

  //step signals
  ledcAttachChannel(AGITATION_MOTOR_STEP, 1000, PWM_RESOLUTION, AGITATION_MOTOR_STEP_CHANNEL);
  ledcAttachChannel(MOTOR_X_STEP, 1000, PWM_RESOLUTION, MOTOR_X_STEP_CHANNEL);
  ledcAttachChannel(MOTOR_Y_STEP, 1000, PWM_RESOLUTION, MOTOR_Y_STEP_CHANNEL);


  // for (int i = 0; i < 100000; i++) {
  //   uint8_t stateX = digitalRead(HORIZONTAL_SWITCH);  //check status of limit switch
  //   Serial.println(stateX);
  // }

  // delay(5000);
}

/*
 *@brief: state machine is either waiting for uart data or moving motors.
 *@author: Dorjee Tenzing
*/
void loop() {
  //state machine to handle the machine operation
  switch (currentState) {
    case waitingState:
      // fill up tempBuffer with serial data
      if (MySerial.available()) {
        // Read the incoming byte
        char incomingByte = MySerial.read();
        tempBuffer[i][j] = incomingByte;
        //Serial.println(incomingByte);
        j++;
        //handle newline
        if (incomingByte == '\n') {
          //Serial.println("testing new line");
          tempBuffer[i][j] = '\0';
          i++;
          j = 0;
        }
        //handle tab operator
        if (incomingByte == '\t') {
          tempBuffer[i][j] = '\0';
          //for (int rep; rep < )
          i = 0;
          j = 0;
          //turn motors on and go to run state
          currentState = runState;
          digitalWrite(MOTOR_ENABLE, 0);
        }
      }
      break;
    case runState:
      //send the protocol name to the touchscreen so it can display the name
      // MySerial.write("T");
      // delay(20);
      // MySerial.println(tempBuffer[0]);


      //auto home first
      finishFlag = autoHome();
      //if autohome didnt finish, go back to the waiting state
      if (!finishFlag) {
        //after protocol finishes, go back to waiting state
        currentState = waitingState;
        memset(tempBuffer, 0, sizeof(tempBuffer));
        //shitty solution to the issue of uart data being sent while motors move
        while (MySerial.available()) {
          MySerial.read();
        }
        break;
      }

      //go line by line through tempBuffer and execute the protocol
      for (int a = 1; a < MAX_LINES; a++) {  //skip first line cuz it is the title
        //handle pause
        if (tempBuffer[a][0] == 'P') {
          //parse uart pause data
          uint8_t pauseDuration = (tempBuffer[a][1] - '0');  // Only duration for pausing

          //send uart data to tell stm32 which protocol is running
          MySerial.write("P");
          delay(20);
          MySerial.println(tempBuffer[a]);

          //perform the pause functon
          finishFlag = pauseMotors(pauseDuration);
        }

        //handle moving
        if (tempBuffer[a][0] == 'M') {
          //parse uart moving data
          uint8_t initialSurfaceTime = ((tempBuffer[a][1] - '0') * 100) + ((tempBuffer[a][2] - '0') * 10) + (tempBuffer[a][3] - '0');  // Initial surface time
          uint8_t speed = (tempBuffer[a][4] - '0');                                                                                    // Speed
          uint8_t stopAtSequences = (tempBuffer[a][5] - '0');                                                                          // Stop at sequences
          uint8_t sequencePauseTime = (tempBuffer[a][6] - '0');                                                                        // Sequence pause time

          //send uart data to tell stm32 which protocol is running
          MySerial.write("M");
          delay(20);
          MySerial.println(tempBuffer[a]);

          //perform the move function
          finishFlag = moveSample(initialSurfaceTime, speed, stopAtSequences, sequencePauseTime);
        }

        //handle agitation
        if (tempBuffer[a][0] == 'B') {
          //parse the agitation uart data
          uint16_t agitateSpeed = (tempBuffer[a][1] - '0');  //you take the index and subtract by null to get the actual number in the struct
          uint8_t agitateDuration = ((tempBuffer[a][2] - '0') * 10) + ((tempBuffer[a][3] - '0'));
          uint8_t totalVolume = ((tempBuffer[a][4] - '0') * 100) + ((tempBuffer[a][5] - '0') * 10) + ((tempBuffer[a][6] - '0'));
          uint8_t percentDepth = ((tempBuffer[a][7] - '0') * 100) + ((tempBuffer[a][8] - '0') * 10) + ((tempBuffer[a][9] - '0'));
          uint8_t pauseDuration = ((tempBuffer[a][10] - '0') * 10) + (tempBuffer[a][11] - '0');
          uint8_t repeat = ((tempBuffer[a][12] - '0') * 10) + (tempBuffer[a][13] - '0');

          //send uart data to tell stm32 which protocol is running
          MySerial.write("B");
          delay(20);
          MySerial.println(tempBuffer[a]);

          //perform the agitation function
          finishFlag = agitateMotors(agitateSpeed, agitateDuration, totalVolume, percentDepth, pauseDuration, repeat);
        }
      }

      //after protocol finishes, go back to waiting state
      currentState = waitingState;
      memset(tempBuffer, 0, sizeof(tempBuffer));
      //shitty solution to the issue of uart data being sent while motors move
      while (MySerial.available()) {
        MySerial.read();
      }

      //send uart data to tell stm32 protocol is finished
      if (finishFlag) {
        MySerial.write("D");
        digitalWrite(MOTOR_ENABLE, 1);
        finishFlag = 0;
      }
      break;
  }
}

/**
 * @brief: move agitaton motor up and down rapidly
 * @param agitateSpeed: speed of motor from 1-9
 * @param agitateDuration: duration of agitation up to 99
 * @param totalVolume: starting bottom location of the agitation. 100 is all the way down
 * @param percentDepth: how far up relative to the start bottom location of agitation. 100 is all the way back up.
 * @param pauseDuration: how long to pause inbetween agitation steps, up to 99
 * @param repeat: how many times the agitation is repated, up to 99
 * @retval: 1 if finished, 0 if stopped by touchscreen
 * @author: Code written by Gregory Ziegler, reviewed and commented by Dorjee Tenzing
 */
uint8_t agitateMotors(uint16_t agitateSpeed, uint8_t agitateDuration, uint8_t totalVolume, uint8_t percentDepth, uint8_t pauseDuration, uint8_t repeat) {

  //autohome and setup variables
  delay(200);
  homeAgitation();
  ledcDetach(AGITATION_MOTOR_STEP);  // Releases control from PWM
  stepper.enableOutputs();

  //some debugging stuff
  Serial.print("Current Position: ");
  Serial.println(stepper.currentPosition());
  if (stepper.currentPosition() != 0) {
    stepper.setCurrentPosition(0);
  }

  // Convert input speed to a usable frequnecy
  uint16_t agitationFrequency = mapSpeedAgitation(agitateSpeed);  // Frequency in steps/sec

  //convert input volume and depth into corresponding values in real life units of mm
  float depth_mm = (float)HEIGHT_OF_TEST_TUBE * (totalVolume / 100.0);  //bottom of agitation relative to absolute zero
  float stroke_mm = depth_mm - (depth_mm * (percentDepth / 100.0));     //top of agitation relative to bottom

  //convert mm values to steps
  uint32_t init_depth = depth_mm / 0.00625;     //bottom of agitation relative to absolute zero in steps
  uint32_t stroke_steps = stroke_mm / 0.00625;  //top of agitation relative to bottom in steps


  // Setup stepper
  stepper.setMaxSpeed(20000);        // initial slow speed for positioning
  stepper.setAcceleration(3000000);  // Very aggressive acceleration

  // Define positions
  long top = stroke_steps;   //top of agitation is stroke steps
  long bottom = init_depth;  //bottom of agitation is init_depth
  bool movingDown = false;   //agitation starts by moving up


  // agitation starts by moving to the bottom location
  stepper.moveTo(bottom);
  while (stepper.distanceToGo() != 0) {
    stepper.run();
  }

  //didnt we just do this?
  stepper.setMaxSpeed(agitationFrequency);  // High speed target
  stepper.setAcceleration(3000000);         // Very aggressive acceleration

  //send uart data for the stm32 to know we are starting agitation loop
  MySerial.write("B");
  delay(20);
  MySerial.write(agitateDuration);

  //begin agitation loop
  for (uint8_t rep = 0; rep < repeat; rep++) {
    if (rep > 0) {
      MySerial.write("R");
      delay(20);
      uint8_t repeatSendVal = rep + 1;
      MySerial.print(repeatSendVal);
    }

    unsigned long startTime = millis();  //get time
    movingDown = false;                  //always start agitation by going up
    stepper.moveTo(top);                 //First move up ????
    while (millis() - startTime < (agitateDuration * 1000)) {
      //run the motor until we hit top or bottom, then switch directions
      stepper.run();
      if (stepper.distanceToGo() == 0) {
        stepper.moveTo(movingDown ? top : bottom);
        movingDown = !movingDown;
      }

      //check for the touchscreen sending a stop signal
      if (checkStopMotorsMessage()) {
        ledcAttachChannel(AGITATION_MOTOR_STEP, 1000, PWM_RESOLUTION, AGITATION_MOTOR_STEP_CHANNEL);
        return 0;
      }
    }
    //pause motors after at top of test tube after agitation
    stepper.moveTo(top);
    while (stepper.distanceToGo() != 0) {
      stepper.run();
    }
    movingDown = true;  // why?
    pauseMotors(pauseDuration);
    //stepper.run();
  }

  stepper.stop();  //hault
  // Reattach PWM and rehome agitation motor
  ledcAttachChannel(AGITATION_MOTOR_STEP, 1000, PWM_RESOLUTION, AGITATION_MOTOR_STEP_CHANNEL);
  homeAgitation();  //
  return 1;
}

/**
  * from here, assume that the combs in question will be clamped with the magnets until the very end
 * @brief: maps agitation speed to frequency for motor step signal.
 * num1 and num2 are the integer ranges of speed, num3 and num4 are the frequency ranges
 * @param value: speed value from 1-9
 * @retval: frequency for motor step signal
 * @author: Gregory Ziegler
 */

unsigned int mapSpeedAgitation(float value) {
  return (value - 1) * (55000 - 20000) / (9 - 1) + 20000;
}

/**
  * from here, assume that the combs in question will be clamped with the magnets until the very end
 * @brief:slowly moves the magnets into the sampletray and transports sample to next well"M742193"
 * @param   initialSurfaceTime first 3 numbers
 * @param speed fourth number
 * @param stopAtSequences fifth number
 * @param sequencePauseTime sixth number
 * @retval: 1 if finished, 0 if error
 * @author: Code written by Gregory Ziegler
 */
uint8_t moveSample(uint8_t initialSurfaceTime, uint8_t speed, uint8_t stopAtSequences, uint8_t sequencePauseTime) {
  //fully init into the funciton
  delay(1000);
  if (checkStopMotorsMessage()) {
    return 0;
  }
  //homeAgitation();  // home the agitation motor and wait
  //delay(2000);
  // if (checkStopMotorsMessage()) {
  //   return 0;
  // }
  //if user inputs 0 stops, switch it to 1
  if (stopAtSequences == 0) {
    stopAtSequences = 1;
  }
  //the positions to stop at is determined by the number of stops
  //float pos = range / stopAtSequences;
  uint8_t pos = floor(HEIGHT_OF_TEST_TUBE / stopAtSequences);
  for (int i = 0; i < stopAtSequences; i++) {
    moveMotorY(HIGH, speed, pos);     //increment motor
    delay(sequencePauseTime * 1000);  //hold here for however long specified
    if (checkStopMotorsMessage()) {
      return 0;
    }
  }


  //moving sequence
  moveMotorY(LOW, 1, pos * stopAtSequences);
  //moveMotorY(LOW, 1, range);  //after the beads are magnatized, hove the body up slowly
  delay(2000);  //delay to make sure the liquid stays
  if (checkStopMotorsMessage()) {
    return 0;
  }
  homeAgitation();
  //above works time for step 2, move to the right and fill the next Well
  moveMotorX(HIGH, 1, 9);  //move to next Well
  delay(2000);             //wait for smoothness
  if (checkStopMotorsMessage()) {
    return 0;
  }

  //greg what are these movements for?
  moveMotorY(HIGH, 1, 20);  //position just above the wells
  //fill other well sequence
  moveMotorA(HIGH, 2, 16);
  moveMotorY(LOW, 1, 20);
  homeAgitation();  //should we add agitation home? idk whats going on

  delay(initialSurfaceTime);
  if (checkStopMotorsMessage()) {
    return 0;
  }
  return 1;
}




/**
 * @brief:runs motor in home direction until a limit switch is hit
 * @param none
 * @retval: 1 if finished, 0 if error
 * @author: Gregory Ziegler
 */
uint8_t autoHome(void) {
  Serial.println("Start Homing");

  int motorSequence = 0;  //controls sequence of motors homing.
  delay(200);             //greg why delay here
  if (checkStopMotorsMessage()) {
    return 0;
  }
  /****** move y motor up in case it last left off in the test tray ******/
  moveMotorY(LOW, 4, HEIGHT_OF_TEST_TUBE + 5);
  delay(200);  //greg why delay here, doesnt the moveMotorY function already handle movement
  if (checkStopMotorsMessage()) {
    return 0;
  }
  /********** AGITATION MOTOR HOMING **************/
  if (motorSequence == 0) {
    // Low is Up, High is DOwn
    //Serial.println("Homing Agitation");
    digitalWrite(AGITATION_MOTOR_DIR, LOW);      //LOW is the home DIrection
    ledcWriteTone(AGITATION_MOTOR_STEP, 10000);  // Drive motor
    // determine if it is pressed
    uint8_t stateA = digitalRead(AGITATION_SWITCH);
    //if the state of the limit switch is high that means it has been pressed
    while (1) {
      stateA = digitalRead(AGITATION_SWITCH);
      if (stateA != 1) {

        //turn off motor in this event
        digitalWrite(AGITATION_MOTOR_DIR, HIGH);
        ledcWriteTone(AGITATION_MOTOR_STEP, 0);
        moveMotorA(HIGH, 8, 2);  //nudge
        motorSequence = 1;
        break;
      } else {
        //Serial.println("Limit switch is currently Untouched");
        continue;
      }
    }
  }
  if (checkStopMotorsMessage()) {
    return 0;
  }

  /********** Move Motor Left **************/
  if (motorSequence == 1) {
    //Serial.println("Homing Y Axis");
    //Right is Low, High is Left
    ledcWriteTone(MOTOR_X_STEP, 800);  // Drive motor
    digitalWrite(MOTOR_X_DIR, LOW);    //home direction is left = LOW
    //if the state of the limit switch is high that means it has been pressed
    uint8_t stateX = digitalRead(HORIZONTAL_SWITCH);  //check status of limit switch
    while (1) {
      //the motor should be running the whole time that the limit switch is untouched
      // for (int i =0; i<10000; i++) {
      //        uint8_t stateX = digitalRead(HORIZONTAL_SWITCH);  //check status of limit switch
      //        Serial.println(stateX);
      // }
      delay(10);
      stateX = digitalRead(HORIZONTAL_SWITCH);  //check status of limit switch
      // Serial.print("Limit switch X => ");
      // Serial.println(stateX);

      if (stateX == 0) {
        // Serial.println("Limit switch is currently Touched");
        // Serial.print("Final limit switch value X => ");
        // Serial.println(stateX);

        //turn off motor in this event
        digitalWrite(MOTOR_X_DIR, HIGH);
        ledcWriteTone(MOTOR_X_STEP, 0);  //
        moveMotorX(HIGH, 2, 2);          //nudge motor to the right so it's not on the limit switch
        motorSequence = 2;
        break;
      }
    }
  }
  if (checkStopMotorsMessage()) {
    return 0;
  }

  /************ Move Motor Down ************/
  if (motorSequence == 2) {
    //Serial.println("Homing X Axis");
    //Low is Up and High is Down
    ledcWriteTone(MOTOR_Y_STEP, 800);  // Drive motor
    digitalWrite(MOTOR_Y_DIR, HIGH);   //home direction is Down = High

    uint8_t stateY = digitalRead(VERTICAL_SWITCH);  //read status of limit switch

    //if the state of the limit switch is high that means it has been pressed
    while (1) {
      delay(10);
      stateY = digitalRead(VERTICAL_SWITCH);  //read status of limit switch
      if (stateY == 0) {
        Serial.println("Vertical Limit switch is currently Touched");
        //turn off motor in this event
        digitalWrite(MOTOR_Y_DIR, HIGH);
        ledcWriteTone(MOTOR_Y_STEP, 0);  //

        moveMotorY(LOW, 4, 3);  //nudge motor to the right so it's not on the limit switch

        break;
      } else {
        //Serial.println("Limit switch is currently Untouched");
        continue;
      }
    }
  }
  if (checkStopMotorsMessage()) {
    return 0;
  }

  //homing complete begin phase 2

  //move all three axis to there init positions

  moveMotorY(LOW, 4, VERTICAL_ABOVE_TEST_TRAY_LOCATION);     // motor y to init position
  moveMotorX(HIGH, 5, HORIZONTAL_ABOVE_TEST_TRAY_LOCATION);  //motor x to init position

  homeAgitation();

  if (checkStopMotorsMessage()) {
    return 0;
  }
  return 1;
}

/**
 * @brief: take in a distance and move the gantry head that amount
 * note this particular motor driver is quarter microsteped.
 * @param distance
 * @retval: none
 * @author: Gregory Ziegler
 */
void moveMotorA(int DIR, uint32_t speed, float distance) {  //
  // convert distance to steps. for now i'm keeping it in number of revolutions
  uint32_t steps = distanceToStepsA(distance);
  uint16_t stepFrequency = mapSpeedA(speed);          // adjust to control speed (Hz)
  float secondsToRun = (float)steps / stepFrequency;  // time = steps / freq
  uint32_t durationMs = (uint32_t)(secondsToRun * 1000);

  digitalWrite(AGITATION_MOTOR_DIR, DIR);              // set direction
  ledcWriteTone(AGITATION_MOTOR_STEP, stepFrequency);  // start step pulses

  delay(durationMs);  // run long enough to cover desired steps

  ledcWriteTone(AGITATION_MOTOR_STEP, 0);  // stop step pulses
}
// angle (degrees) = (arc length / radius) * (180 / π)
uint32_t distanceToStepsA(float distance)  // about 8.75mm
{
  //return distance * 200 * 16; // one rotation
  return (uint32_t)(distance * (3200.0 / 20.0) + 0.5f);
}
// num1 and num2 are the integer ranges of speed, num3 and num4 are the frequency ranges
unsigned int mapSpeedA(float value) {
  return (value - 1) * (12000 - 5000) / (9 - 1) + 5000;
}
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

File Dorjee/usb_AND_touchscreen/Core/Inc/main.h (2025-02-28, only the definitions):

#define PC14_OSC32_IN_Pin GPIO_PIN_14
#define PC14_OSC32_IN_GPIO_Port GPIOC
#define PC15_OSC32_OUT_Pin GPIO_PIN_15
#define PC15_OSC32_OUT_GPIO_Port GPIOC
#define A0_Pin GPIO_PIN_0
#define A0_GPIO_Port GPIOF
#define A1_Pin GPIO_PIN_1
#define A1_GPIO_Port GPIOF
#define A2_Pin GPIO_PIN_2
#define A2_GPIO_Port GPIOF
#define A3_Pin GPIO_PIN_3
#define A3_GPIO_Port GPIOF
#define A4_Pin GPIO_PIN_4
#define A4_GPIO_Port GPIOF
#define A5_Pin GPIO_PIN_5
#define A5_GPIO_Port GPIOF
#define SPI5_SCK_Pin GPIO_PIN_7
#define SPI5_SCK_GPIO_Port GPIOF
#define SPI5_MISO_Pin GPIO_PIN_8
#define SPI5_MISO_GPIO_Port GPIOF
#define SPI5_MOSI_Pin GPIO_PIN_9
#define SPI5_MOSI_GPIO_Port GPIOF
#define ENABLE_Pin GPIO_PIN_10
#define ENABLE_GPIO_Port GPIOF
#define PH0_OSC_IN_Pin GPIO_PIN_0
#define PH0_OSC_IN_GPIO_Port GPIOH
#define PH1_OSC_OUT_Pin GPIO_PIN_1
#define PH1_OSC_OUT_GPIO_Port GPIOH
#define SDNWE_Pin GPIO_PIN_0
#define SDNWE_GPIO_Port GPIOC
#define NCS_MEMS_SPI_Pin GPIO_PIN_1
#define NCS_MEMS_SPI_GPIO_Port GPIOC
#define CSX_Pin GPIO_PIN_2
#define CSX_GPIO_Port GPIOC
#define B1_Pin GPIO_PIN_0
#define B1_GPIO_Port GPIOA
#define MEMS_INT1_Pin GPIO_PIN_1
#define MEMS_INT1_GPIO_Port GPIOA
#define MEMS_INT2_Pin GPIO_PIN_2
#define MEMS_INT2_GPIO_Port GPIOA
#define B5_Pin GPIO_PIN_3
#define B5_GPIO_Port GPIOA
#define VSYNC_Pin GPIO_PIN_4
#define VSYNC_GPIO_Port GPIOA
#define G2_Pin GPIO_PIN_6
#define G2_GPIO_Port GPIOA
#define ACP_RST_Pin GPIO_PIN_7
#define ACP_RST_GPIO_Port GPIOA
#define OTG_FS_PSO_Pin GPIO_PIN_4
#define OTG_FS_PSO_GPIO_Port GPIOC
#define OTG_FS_OC_Pin GPIO_PIN_5
#define OTG_FS_OC_GPIO_Port GPIOC
#define R3_Pin GPIO_PIN_0
#define R3_GPIO_Port GPIOB
#define R6_Pin GPIO_PIN_1
#define R6_GPIO_Port GPIOB
#define BOOT1_Pin GPIO_PIN_2
#define BOOT1_GPIO_Port GPIOB
#define SDNRAS_Pin GPIO_PIN_11
#define SDNRAS_GPIO_Port GPIOF
#define A6_Pin GPIO_PIN_12
#define A6_GPIO_Port GPIOF
#define A7_Pin GPIO_PIN_13
#define A7_GPIO_Port GPIOF
#define A8_Pin GPIO_PIN_14
#define A8_GPIO_Port GPIOF
#define A9_Pin GPIO_PIN_15
#define A9_GPIO_Port GPIOF
#define A10_Pin GPIO_PIN_0
#define A10_GPIO_Port GPIOG
#define A11_Pin GPIO_PIN_1
#define A11_GPIO_Port GPIOG
#define D4_Pin GPIO_PIN_7
#define D4_GPIO_Port GPIOE
#define D5_Pin GPIO_PIN_8
#define D5_GPIO_Port GPIOE
#define D6_Pin GPIO_PIN_9
#define D6_GPIO_Port GPIOE
#define D7_Pin GPIO_PIN_10
#define D7_GPIO_Port GPIOE
#define D8_Pin GPIO_PIN_11
#define D8_GPIO_Port GPIOE
#define D9_Pin GPIO_PIN_12
#define D9_GPIO_Port GPIOE
#define D10_Pin GPIO_PIN_13
#define D10_GPIO_Port GPIOE
#define D11_Pin GPIO_PIN_14
#define D11_GPIO_Port GPIOE
#define D12_Pin GPIO_PIN_15
#define D12_GPIO_Port GPIOE
#define G4_Pin GPIO_PIN_10
#define G4_GPIO_Port GPIOB
#define G5_Pin GPIO_PIN_11
#define G5_GPIO_Port GPIOB
#define OTG_HS_ID_Pin GPIO_PIN_12
#define OTG_HS_ID_GPIO_Port GPIOB
#define VBUS_HS_Pin GPIO_PIN_13
#define VBUS_HS_GPIO_Port GPIOB
#define OTG_HS_DM_Pin GPIO_PIN_14
#define OTG_HS_DM_GPIO_Port GPIOB
#define OTG_HS_DP_Pin GPIO_PIN_15
#define OTG_HS_DP_GPIO_Port GPIOB
#define D13_Pin GPIO_PIN_8
#define D13_GPIO_Port GPIOD
#define D14_Pin GPIO_PIN_9
#define D14_GPIO_Port GPIOD
#define D15_Pin GPIO_PIN_10
#define D15_GPIO_Port GPIOD
#define TE_Pin GPIO_PIN_11
#define TE_GPIO_Port GPIOD
#define RDX_Pin GPIO_PIN_12
#define RDX_GPIO_Port GPIOD
#define WRX_DCX_Pin GPIO_PIN_13
#define WRX_DCX_GPIO_Port GPIOD
#define D0_Pin GPIO_PIN_14
#define D0_GPIO_Port GPIOD
#define D1_Pin GPIO_PIN_15
#define D1_GPIO_Port GPIOD
#define BA0_Pin GPIO_PIN_4
#define BA0_GPIO_Port GPIOG
#define BA1_Pin GPIO_PIN_5
#define BA1_GPIO_Port GPIOG
#define R7_Pin GPIO_PIN_6
#define R7_GPIO_Port GPIOG
#define DOTCLK_Pin GPIO_PIN_7
#define DOTCLK_GPIO_Port GPIOG
#define SDCLK_Pin GPIO_PIN_8
#define SDCLK_GPIO_Port GPIOG
#define HSYNC_Pin GPIO_PIN_6
#define HSYNC_GPIO_Port GPIOC
#define G6_Pin GPIO_PIN_7
#define G6_GPIO_Port GPIOC
#define I2C3_SDA_Pin GPIO_PIN_9
#define I2C3_SDA_GPIO_Port GPIOC
#define I2C3_SCL_Pin GPIO_PIN_8
#define I2C3_SCL_GPIO_Port GPIOA
#define STLINK_RX_Pin GPIO_PIN_9
#define STLINK_RX_GPIO_Port GPIOA
#define STLINK_TX_Pin GPIO_PIN_10
#define STLINK_TX_GPIO_Port GPIOA
#define R4_Pin GPIO_PIN_11
#define R4_GPIO_Port GPIOA
#define R5_Pin GPIO_PIN_12
#define R5_GPIO_Port GPIOA
#define SWDIO_Pin GPIO_PIN_13
#define SWDIO_GPIO_Port GPIOA
#define SWCLK_Pin GPIO_PIN_14
#define SWCLK_GPIO_Port GPIOA
#define TP_INT1_Pin GPIO_PIN_15
#define TP_INT1_GPIO_Port GPIOA
#define R2_Pin GPIO_PIN_10
#define R2_GPIO_Port GPIOC
#define D2_Pin GPIO_PIN_0
#define D2_GPIO_Port GPIOD
#define D3_Pin GPIO_PIN_1
#define D3_GPIO_Port GPIOD
#define G7_Pin GPIO_PIN_3
#define G7_GPIO_Port GPIOD
#define B2_Pin GPIO_PIN_6
#define B2_GPIO_Port GPIOD
#define G3_Pin GPIO_PIN_10
#define G3_GPIO_Port GPIOG
#define B3_Pin GPIO_PIN_11
#define B3_GPIO_Port GPIOG
#define B4_Pin GPIO_PIN_12
#define B4_GPIO_Port GPIOG
#define LD3_Pin GPIO_PIN_13
#define LD3_GPIO_Port GPIOG
#define LD4_Pin GPIO_PIN_14
#define LD4_GPIO_Port GPIOG
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

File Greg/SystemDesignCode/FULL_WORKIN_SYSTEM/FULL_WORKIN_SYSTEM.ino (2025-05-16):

/************
4/3/25
Gregory Ziegler + Dorjee Tenzing
Overview:
Create premade protocolInstructions that consist of three operations: agitate, pause, bind
Write a state machine that calls existing motor functions with defined inputs and outputs
IE host a diddy party in each well specified by diddy. Check on the hoes, then go to the next house.
*************/

#include <ezButton.h>
#include <AccelStepper.h>

#define MAX_LINE_LENGTH 32
#define MAX_LINES 100

const int AGITATION_MOTOR_STEP = 19;
const int AGITATION_MOTOR_DIR = 18;

const int MOTOR_X_STEP = 5;
const int MOTOR_X_DIR = 4;

const int MOTOR_Y_STEP = 2;  //
const int MOTOR_Y_DIR = 3;   //
const int AGITATION_MOTOR_STEP_CHANNEL = 2;
const int MOTOR_X_STEP_CHANNEL = 4;
const int MOTOR_Y_STEP_CHANNEL = 3;

const int AGITATION_SWITCH = 15;
const int VERTICAL_SWITCH = 6;
const int HORIZONTAL_SWITCH = 7;

const int MOTOR_ENABLE = 22;


AccelStepper stepper(AccelStepper::DRIVER, AGITATION_MOTOR_STEP, AGITATION_MOTOR_DIR);
ezButton limitSwitchX(HORIZONTAL_SWITCH);         // create ezButton object that attach to ESP32 pin GPIO5
ezButton limitSwitchY(VERTICAL_SWITCH);           // create ezButton object that attach to ESP32 pin GPIO6
ezButton limitSwitchAgitation(AGITATION_SWITCH);  // create ezButton object that attach to ESP32 pin GPIO7

// HardwareSerial mySerial(1);

// Initialize the tempBuffer with nulls ('\0')
char tempBuffer[MAX_LINES][MAX_LINE_LENGTH] = { { '\0' } };
// memset(tempBuffer, 0, sizeof(tempBuffer));
uint8_t startFlag = 0;
uint8_t i = 0;
uint8_t j = 0;

// types of protocolInstructions
enum ProtocolType {
  AGITATION,  // 'B'
  PAUSING,    // 'P'
  MOVING,     // 'M'
  INVALID     // For unknown protocol types
};
// Structure to store protocol properties
struct Protocol {
  ProtocolType type;
  uint8_t volume;
  uint8_t percentVolume;
  uint8_t speed;
  uint8_t duration;
  uint8_t initialSurfaceTime;
  uint8_t stopAtSequences;
  uint8_t sequencePauseTime;
};

// Protocol Array
char *protocolInstructions[] = {
  "B930100050", "P10", "B930100050", "P10", "M010435", "B930100050", "P10"
};

// global size of protocolInstructions
int size = sizeof(protocolInstructions) / sizeof(protocolInstructions[0]);  // Get number of elements


// Initialize the tempBuffer with nulls ('\0')

void setup() {
  // Set up UART and GPIO

  digitalWrite(MOTOR_ENABLE, 0);

  Serial.begin(115200);
  limitSwitchAgitation.setDebounceTime(50);  // set debounce time of limit switch to 50 milliseconds
  limitSwitchX.setDebounceTime(50);
  limitSwitchY.setDebounceTime(50);
  pinMode(AGITATION_MOTOR_DIR, OUTPUT);
  pinMode(MOTOR_Y_DIR, OUTPUT);
  pinMode(MOTOR_X_DIR, OUTPUT);
  //limit switch pins set to input
  pinMode(HORIZONTAL_SWITCH, INPUT_PULLDOWN);
  pinMode(VERTICAL_SWITCH, INPUT_PULLDOWN);
  pinMode(AGITATION_SWITCH, INPUT_PULLDOWN);

  // Setup  Motor Step Signal
  ledcAttachChannel(AGITATION_MOTOR_STEP, 1000, 8, AGITATION_MOTOR_STEP_CHANNEL);
  ledcAttachChannel(MOTOR_X_STEP, 1000, 8, MOTOR_X_STEP_CHANNEL);
  ledcAttachChannel(MOTOR_Y_STEP, 1000, 8, MOTOR_Y_STEP_CHANNEL);

  /** USEFUL FUNCTIONS:
   * ledcWriteTone(AGITATION_MOTOR_STEP, 1000);
   * ledcChangeFrequency(AGITATION_MOTOR_DIR, 10, 8);
   */

  /*********** RUN MAIN TEST ***********/
  pinMode(MOTOR_ENABLE, OUTPUT);
  // Fill in tempBuffer with premade protocol
  strcpy(tempBuffer[0], "P3");
  strcpy(tempBuffer[1], "A340532");
  uint8_t i = 0;

  // for (i = 0; i, MAX_LINES; i++) {
  //   //handle pause operation: P7. Input: Duration
  //   if (tempBuffer[i][0] == 'P') {
  //     uint8_t pauseDuration = tempBuffer[i][1] - '0';  //convert from ascii to int
  //     pauseMotors(pauseDuration);
  //   }

  //   //handle agitate operation: A74. Inputs: Agitation speed, agitation duration
  //   if (tempBuffer[i][0] == 'A') {
  //     uint8_t agitateSpeed = tempBuffer[i][4] - '0';                                         //extract speed
  //     uint8_t agitateDuration = ((tempBuffer[i][5] - '0') * 10) + (tempBuffer[i][6] - '0');  //extract duration
  //     uint8_t totalVolume = tempBuffer[i][1] - '0';                                          //extract total volume
  //     uint8_t percentVolume = ((tempBuffer[i][2] - '0') * 10) + (tempBuffer[i][3] - '0');    //extract percent volumt
  //     agitateMotors(agitateSpeed, agitateDuration, totalVolume, percentVolume);
  //   }

  //   //handle bind operation: B7. Inputs: Bind duration
  //   if (tempBuffer[i][0] == 'B') {
  //     uint8_t bindDuration = tempBuffer[i][0];
  //   }
  // }


  // /*Limit Switch Test Case*/
  //fun
  //sidequest




  /*WORKS this block FUcking Works. 
  // digitalWrite(AGITATION_MOTOR_DIR, HIGH);
  // ledcWriteTone(AGITATION_MOTOR_STEP,5000);



  /*Test Protocol hard code functions
    */
  // Serial.println("Hello World");
  // autoHome();
  // agitateMotors(9, 30, 100, 100);
  // moveSample(010, 4, 3, 5);
  // autoHome();
  //homeAgitation();
  // autoHome();
  while (1) {
    runASAT();
  }

  // autoHome();
  // agitateMotors(9, 30, 100, 100);
  // end setup
}
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

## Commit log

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2025-02-28 going to start using git now. current progress is the touchscreen has 10 pages, qr scanner uploads to any open slot
2025-02-28 first commit of control state machine on arduino ide. the parsing is working, but nothing else is working
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2025-04-03 my changes
    [scraper.gcode.3mf]
2025-04-05 touchscreen works! also got the swd trace printing to work! going to start adding some buttons to sync up the touchscreen, lcd display and printing together.
2025-04-05 next and back buttons working. i have a lot of transferring code to do... this is good for tonight
2025-04-08 updated code for Alex to look at. i think the horizontal and vertical motor commands are working, but need to double check tomorrow
2025-04-12 The solution to agitation motor achieving top speed: accelerate it from a low frequency to goal frequency. the new issue is the agitation motor wont actually agitate properly. gonna start writing int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
    [agitation_motor_not_working.ino]
2025-04-15 adding motor test files into this folder that correlate with a spreadsheet. row3 is the first test and it is smooth
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2025-04-18 testing sharing kicad files. schematic currently has a rough microcontroller circuit. stepper driver and buck regulator pages need to be added
    [power_supply_v1.kicad_pcb, power_supply_v1.kicad_sch]
2025-04-18 trying a different file structure
    [power_supply_v1.kicad_sch]
2025-04-18 check the README. basically did rough draft of stepper motor section of schematic and need double checking
2025-04-18 small updates made to schematic. still need to continue reading the datasheet and understand the physics behind each decision made
2025-04-21 three new files. the one called clean is the onyl relevant file. it can run a premade protocol of multiple lines. need to test it on the actual motor tomorrow
2025-04-21 there was one typo. now it will compile and run the premade protocols. need to test with motor tomorrow
2025-04-21 the test_state_machine file works on the oscilloscope. need to test with actual motor, but that would come after the other files.
2025-04-21 get_num_protocols was written wrong... also the store protocol is also wrong. i have to fix this now, and this is changing a big part of the program flow. i will save this wrong file here.
    [main.c, usb_AND_touchscreen.ioc]
2025-04-21 seemingly fixed it. didnt have to rewrite everything. the issue lied in the way the protocols were being deleted. simplified everything by just rewriting the delete function to shift all protocols in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
    [main.c]
2025-04-21 the protocol storage function was wonky. i simplified it and fixed it. just remember that flash memory has 0xFF and the arrays we create are nulls. that is a headache to deal with, but its whatever
    [main.c]
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2025-05-01 still dont know if these files can even be accessed, but the rough draft of schematic is finished. it needs revision to verify it will actually work. i made a top level page with three supporting pag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
    [Microcontroller.kicad_sch, Power_Supply.kicad_sch, power_supply_v1.kicad_sch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]
2025-05-03 picking footprints. still need buck regulator footprints
    [Microcontroller.kicad_sch, Power_Supply.kicad_sch, power_supply_v1.kicad_pcb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]
2025-05-04 schematic and footprints have been selected. ready to start layout, but always open to changes in schematic
    [Microcontroller.kicad_sch, Power_Supply.kicad_sch, stepperDrivers.kicad_sch]
2025-05-04 changed jcsc to lcsc
    [Microcontroller.kicad_sch, Power_Supply.kicad_sch, stepperDrivers.kicad_sch]
2025-05-04 added 3d models. starting layout, it is hard
    [Microcontroller.kicad_sch, Power_Supply.kicad_sch, power_supply_v1.kicad_pcb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]
2025-05-05 design has been greatly simplified to only one buck regulator for logic components. smps will power the motors. layout has begun and a general component placement is done. needs to be reviewed by tea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
    [Microcontroller.kicad_sch, Motor_Controller_Board_v1.kicad_pcb, Motor_Controller_Board_v1.kicad_sch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]
2025-05-06 discussed with Alex and Mishari. confident in schematic, going to do layout tomorrow
    [Microcontroller.kicad_sch, Motor_Controller_Board_v1.kicad_pcb, Motor_Controller_Board_v1.kicad_sch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]
2025-05-06 general placement done. discuss with teammates tomorrow
    [Download_STP_629105150521_rev1.stp, ESP32-C3-MINI-1U-N4--3DModel-STEP-269445.STEP, ESP32-C6-MINI-1-N4.STEP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]
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2025-05-07 routing 75% finished, but very sloppy
    [Microcontroller.kicad_sch, Motor_Controller_Board_v1.kicad_pcb, Power_Supply.kicad_sch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]
2025-05-08 the file is called motor_controller_v3 because me and mishari have been trading files on google drive. almost finished with layout, mishari will implement petersen's advice and then tomorrow will be 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
    [Microcontroller.kicad_sch, Motor_Controller_Board_v1-BOM.csv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]
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2025-05-09 Mishari added bottom +24V plane instead of 2mm trace and was reviewed by team. Changed enable pins to be controlled by esp32. added potentiometer. alex, mishari and Dorjee all reviewed footprints and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
    [Microcontroller.kicad_sch, Motor_Controller_Board_v1-BOM (1).csv, Motor_Controller_Board_v1-BOM.csv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]
2025-05-09 cleaned up board and switched to horizontal text
    [Microcontroller.kicad_sch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]
2025-05-10 done. see readme for update log
    [Motor_Controller_Board_v1-BOM.csv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]
2025-05-14 fixing Agitation w AccelStepper
    [MainSMV3_copy_20250408153818.ino]
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2025-05-18 touchscreen works with the esp32. queue is seemingly working, stop function is working, and data of the protocol appears crudely on the touchscreen. there seems to be issues with the limit switch not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
    [XPT2046_touch.c, XPT2046_touch.h, bigger_touchscreen.ioc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]
2025-05-20 3d Prints
    [BackGuides.3mf, BackGuides.stl, BackGuidesV2.3mf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]
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2025-05-22 this touchscreen has a timer that counts down, but it refresh the whole page. gonna fix that tomorrow
    [bigger_touchscreen.ioc, main.c]
2025-05-23 agitation is functional. magnetize is functional. the vertical level isnt quite right, lots of bugs still. gonna run full protocol maybe tomorrow
    [changedAgitationScheme.ino]
2025-05-25 motors dont hit the test tray when going laterlly anymore. it seemed to have been an issue with either the autohome not using the bump method to home the agitation motor, using float values for magne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
    [adding_accelstepperY.ino, main.c]
2025-05-29 two changes: altium folder has new touchscreen redesign with qr scanner and fan controlled by mosfet and 2-layer board, still needs finishing touches. motor script is very stable right now, needs mor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
    [MyFootprints.PcbLib, MySymbols.SchLib, Peripherals.SchDoc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]
2025-05-29 almost done. just needs a final check from mishari, me and maybe alex. we are ordering for sure tomorrow!
    [Peripherals.SchDoc, Test project 2 PCB v1.PcbDoc, Test_Project2.PrjPcb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]
2025-06-01 touchscreen seems stable but a few random glitches. the motors seem stable as well. there is some weird issues when an invalid protocol is sent. stilll need more testing, but honestly im almost conte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
    [Peripherals.SchDoc, Pick Place for Touchscreen PCB.csv, Touchcsreen PCB.SchDoc]
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2025-06-11 final code for esp32 and stm32 in the firmware folder. touchscreen pcb v1 and v2 uploaded in a new folder. project is stable and ready to be handed off to gamze
    [MyFootprints.PcbLib, MySymbols.SchLib, Peripherals.SchDoc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]
2025-06-23 used differential pairs for usb, changing mounting holes to be grounded, and removed esd diodes to get better via placements for usb return paths. havent tested it yet
    [MyFootprints.PcbLib, MySymbols.SchLib, Peripherals.SchDoc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]
2025-06-24 yooo i fixed the qr scanner. it actually works. im not sure if its charging, but it almost certainly is. im still not sure which of three fixes i did actually made the difference. its probably the gr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
    [ASATS_Daughterboard_v2.ioc, XPT2046_touch.h, main.c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]

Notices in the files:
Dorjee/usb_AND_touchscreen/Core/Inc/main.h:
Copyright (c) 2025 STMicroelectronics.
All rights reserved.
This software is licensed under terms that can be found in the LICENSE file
